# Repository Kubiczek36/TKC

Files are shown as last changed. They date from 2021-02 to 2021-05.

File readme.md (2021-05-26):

# Projekt dalekohledu pro předmět TKC

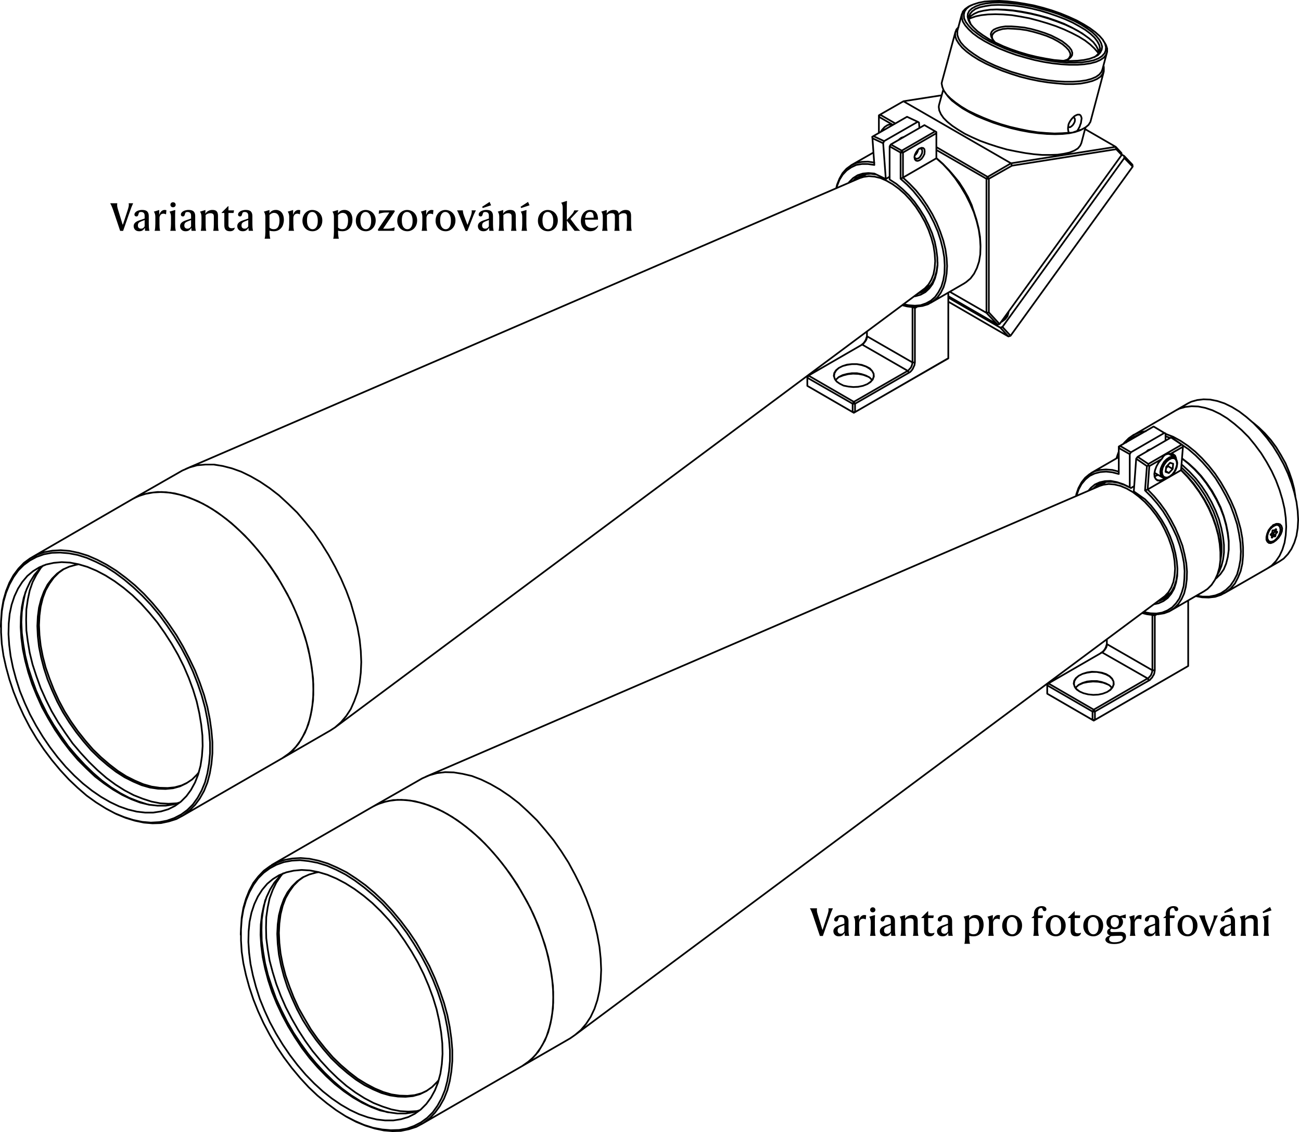
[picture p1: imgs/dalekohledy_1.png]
Dalekohledy


__Co tu naleznete?__

- [Zemax](zemax) - simulace optických vlastností v programu Zemax Optic studio
- [CAD](CAD) - soubory jednotlivých dílů a sestavy v Solidworks
- [imgs](imgs) - ilustrace a obrázky pro tento dokument
- [parts](parts) - dokumentace od výrobce vybraných použitých dílů.

Dalekohled se bude skládat z objektivu a okuláru s určením pro pozemní pozorování. Jako převracecí mechanismus bude použito zrcátko.

[Stránky Meopty](https://eshop.meopta.cz/spektivy/) s inspirací.

## Rozvržení

Konstrukce je inspirována spektivem [Meopta MeoStar S2](https://eshop.meopta.cz/spektivy-meostar-s2/spektiv-meostar-s2-82-hd-sikmy/) tento spektiv má ohniskovou vzdálenost objektivu 439 mm.

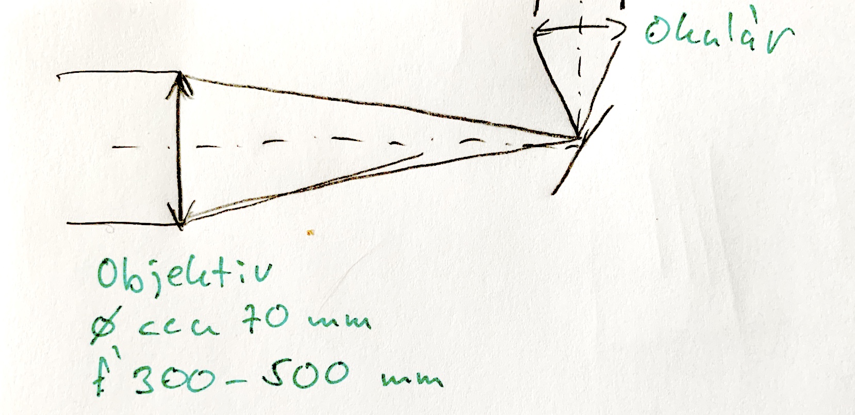
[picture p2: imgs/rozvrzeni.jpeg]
rozvrzeni dalekohledu


Jako objektiv bude sloužit achromatický dublet. Například firma Edmund Optics [nabízí](https://www.edmundoptics.com/c/achromatic-lenses/652/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) takové dublety, které vyhovují průměrem ohniskem. Další výhodou je knihovna dílů v programu Zemax Optics Studio.

Jako okulár se jeví vhodné použít [okulár 20-60x od společnosti Meopta](https://eshop.meopta.cz/spektivy-meostar-s1/okular-20-60x/), navíc spektiv MeoStar S1 má ohniskovou vzdálenost objektivu podobnou námi zvlené vzdálenosti (f' = 329 mm). Díky tomu, že okulár umožňuje zoomovat není zapotřebí měnit okuláry, což umožní redukovat množství prachu, které si při výměně do tubusu dostane.

## Výběr komponent a simulace v programu Zemax

### Objektiv

Z nabídky [vhodných achromatických dubletů](https://www.edmundoptics.com/c/achromatic-lenses/652/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)) firmy Edumnd Optics byl vybrát [dublet](https://www.edmundoptics.com/p/75mm-dia-x-400mm-fl-vis-0deg-coated-achromatic-lens/30848/) s ohniskovou vzdáleností 400 mm a průměru 75 mm s vrstvou propouštející viditelné vlnové délky (400 - 700 nm).

Jelikož je dalekohled určen pro pozemní pozorování, tak je zapotřebí použít jako kameru vhodný fotoaparát. Samotný dublet nemusí mít velké zorné pole, proto stačí použít fotoaparát s čipem micro 4/3, například [Panasonic Lumix GHS5](https://www.fotoskoda.cz/panasonic-lumix-dc-gh5s/). Rozměry čipu 17,3 na 13 mm znemenají, že nejvzdálenější objekt od osy bude 10,8 mm. 

Při simulaci je zapotřebí počítat se závitovým kroužkem upínajícím objektiv do objímky, proto byla zvolena apertura o průměru 73 mm. Při simulaci bylo simulováno zobrazení osového předmětu a dále předmětů vzdálených 1° a 1,5° od osy pro pokrytí celého čipu. 

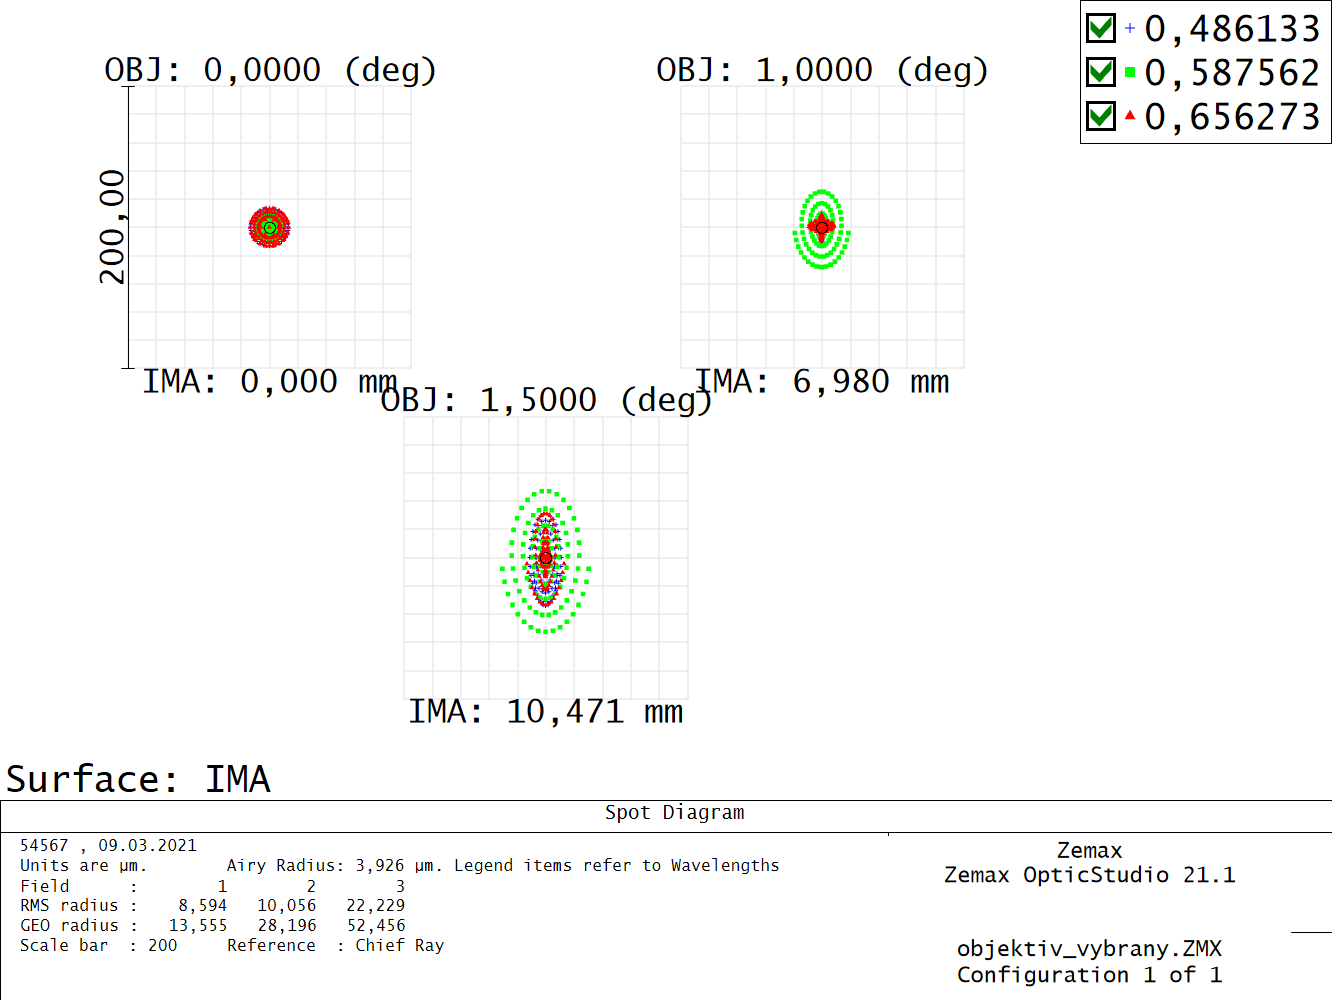
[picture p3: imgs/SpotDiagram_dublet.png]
spot dubletu


Ze spot diagramu lze vidět, že pokud chceme získat kvalitní obraz předmětu umístěného uprostřed zorného pole stačí velikost pixelu okolo 10 μm. To lze ostatně taktéž vidět na závislosti funkce přenosu kontrastu (MTF - Modulated Transfer Funkction) na zorném poli. O clonách pro odstínění parazitních paprsků bude pojednáno později.

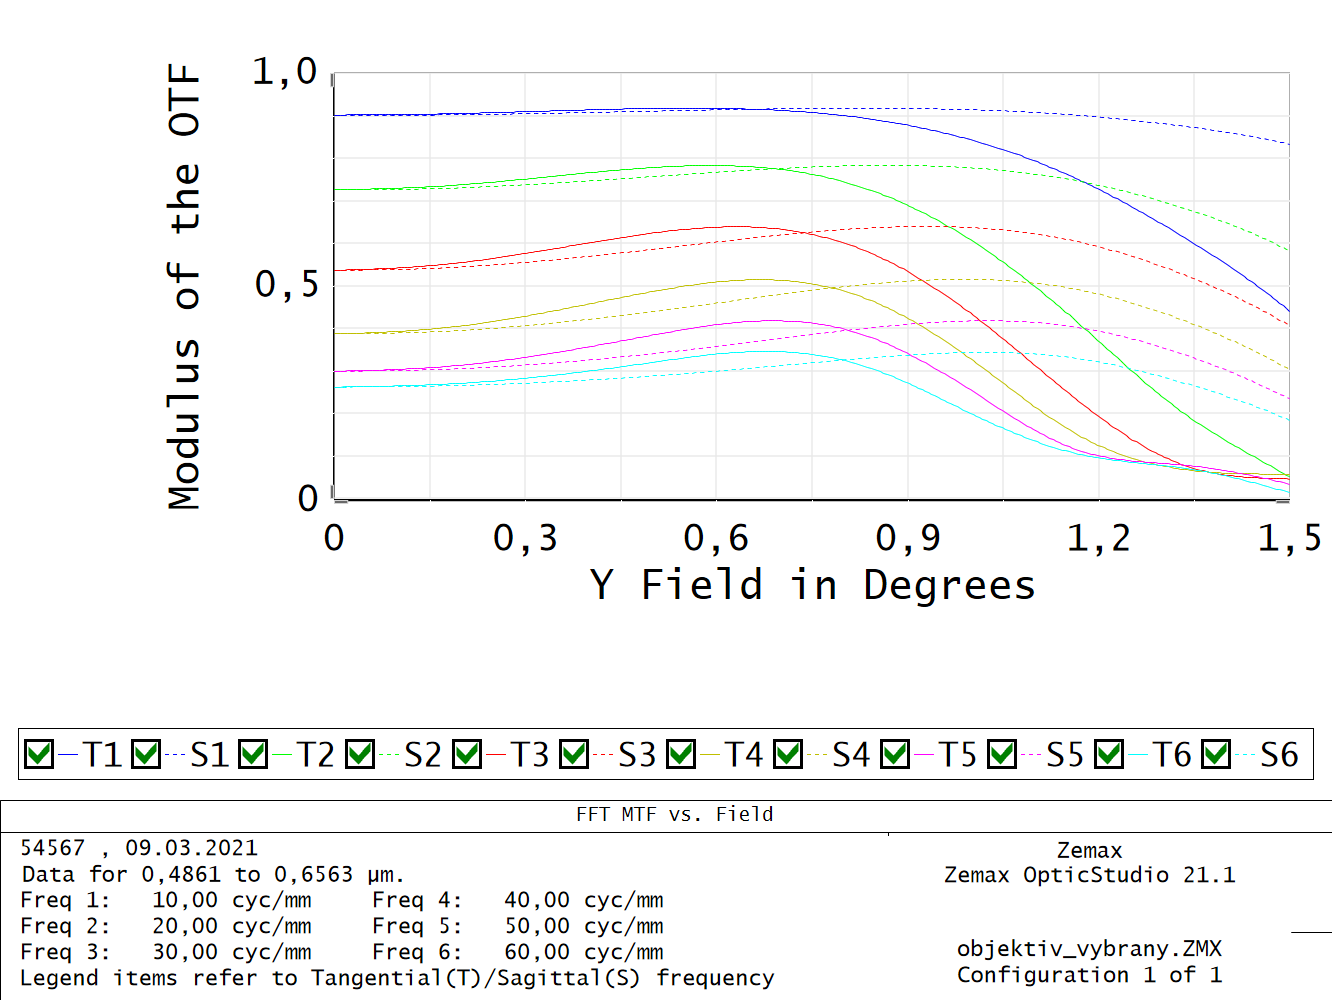
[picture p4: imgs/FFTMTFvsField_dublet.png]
MTF


### Okulár a pozorování okem. 

Při pozorování okem poskytuje samotný objektiv zorné pola max 2,4° Při použití většího zorného pole, je zklenutí pole větší jak podélná sférická vada.

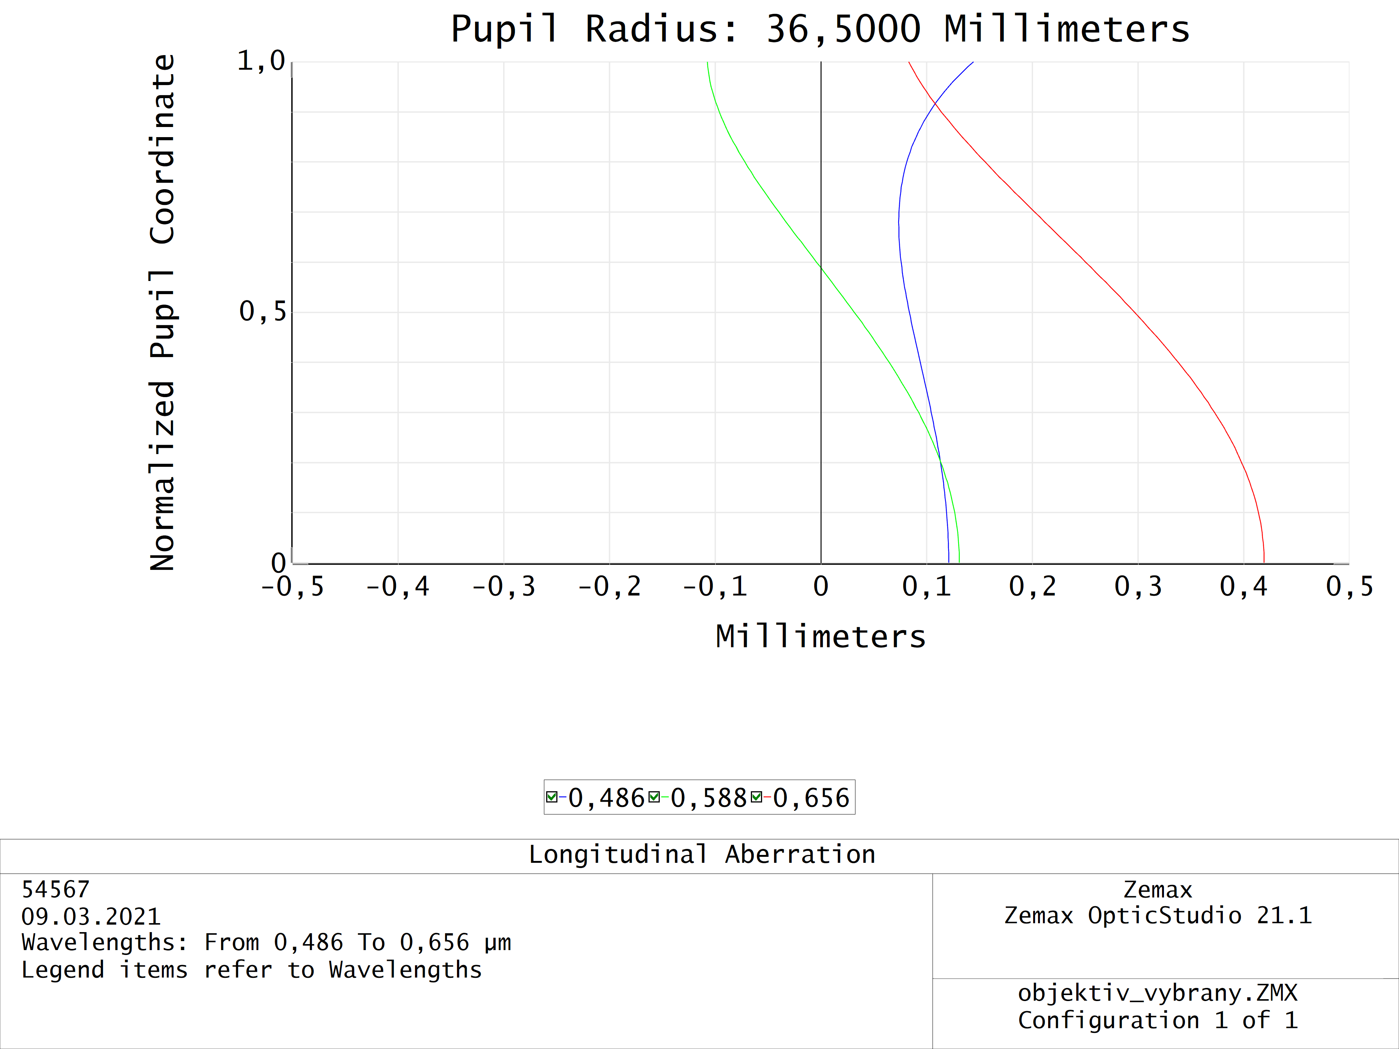
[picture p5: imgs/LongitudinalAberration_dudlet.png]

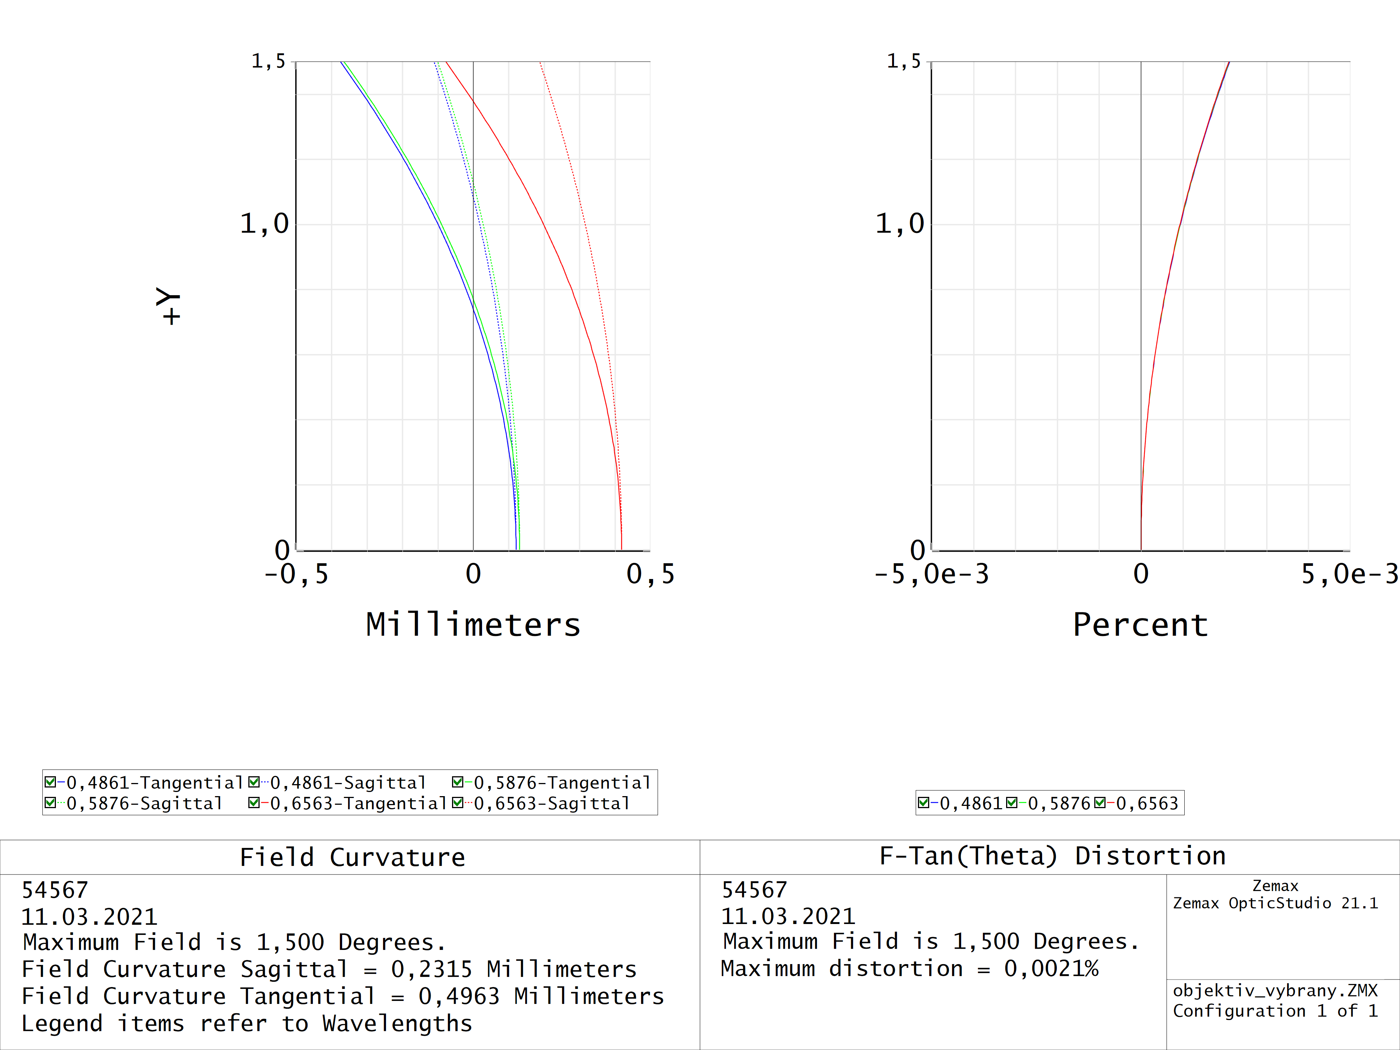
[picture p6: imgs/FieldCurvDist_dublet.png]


Pro převrácení obrazu bylo jako převracecí mechanizmus vybráno zenitové zrcátko. Okulár má ohniskovou vzdálenost 16,2 až 5,55 mm a pro použitý objektiv s ohninskem 400 mm získáváme zorné pole od 1,48° do 0,74° (velikost předmětu v polní rovnině od 5,17 mm do 2,584 mm). Při návrhu mechanické části je počítáno, že ohnisková rovina se nachází v rovině vstupní pupily. Schéma lze vidět na následujícím obrázku.

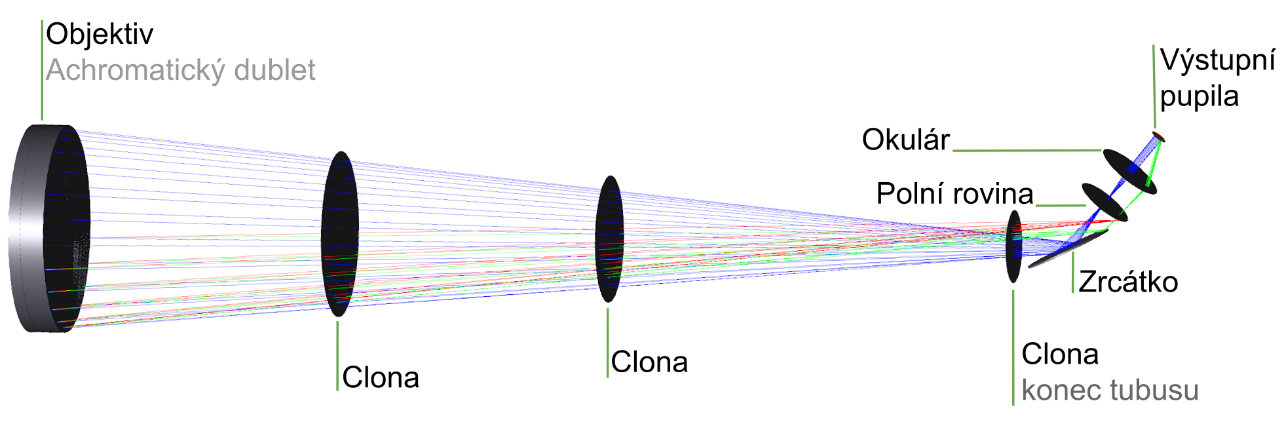
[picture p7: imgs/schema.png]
Schéma dalekohledu


Poloha okuláru je volena tak, aby okulár zobrazoval polní rovinu do konvenční zrakové vzdálenosti 250 mm. Při použití delšího ohniska okuláru (16,2 mm) vzniknou v této rovně stopy velké zhruba 300 μm.
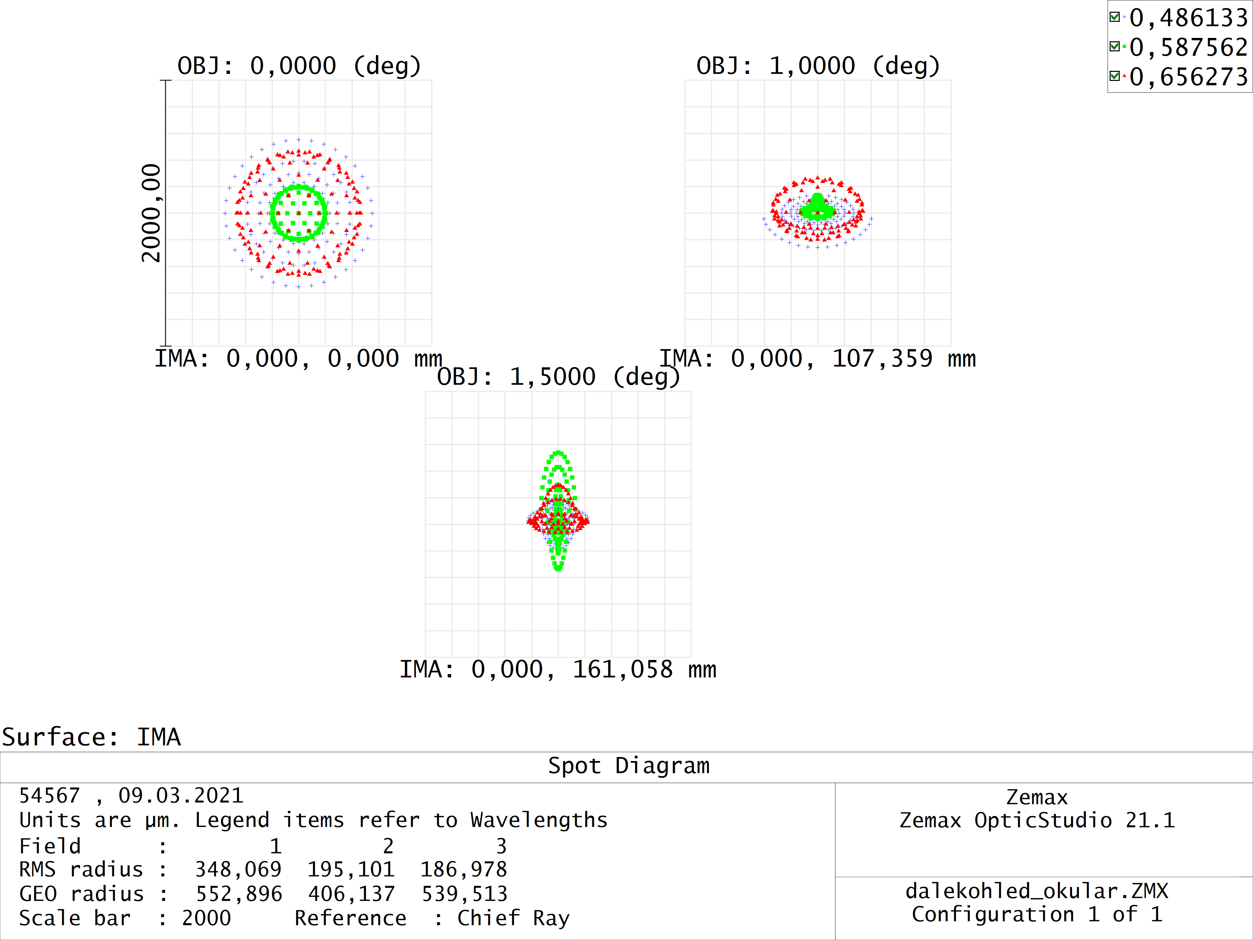
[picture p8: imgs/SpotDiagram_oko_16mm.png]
spot 16 mm


Funkce přenosu kontrastu bude vypadat následujícně.

MTF 16 mm

Při použití nejkratšího ohniska okuláru 5,17 mm se vlivem vinětace omezí zorné pole na zhruba 0,4°.

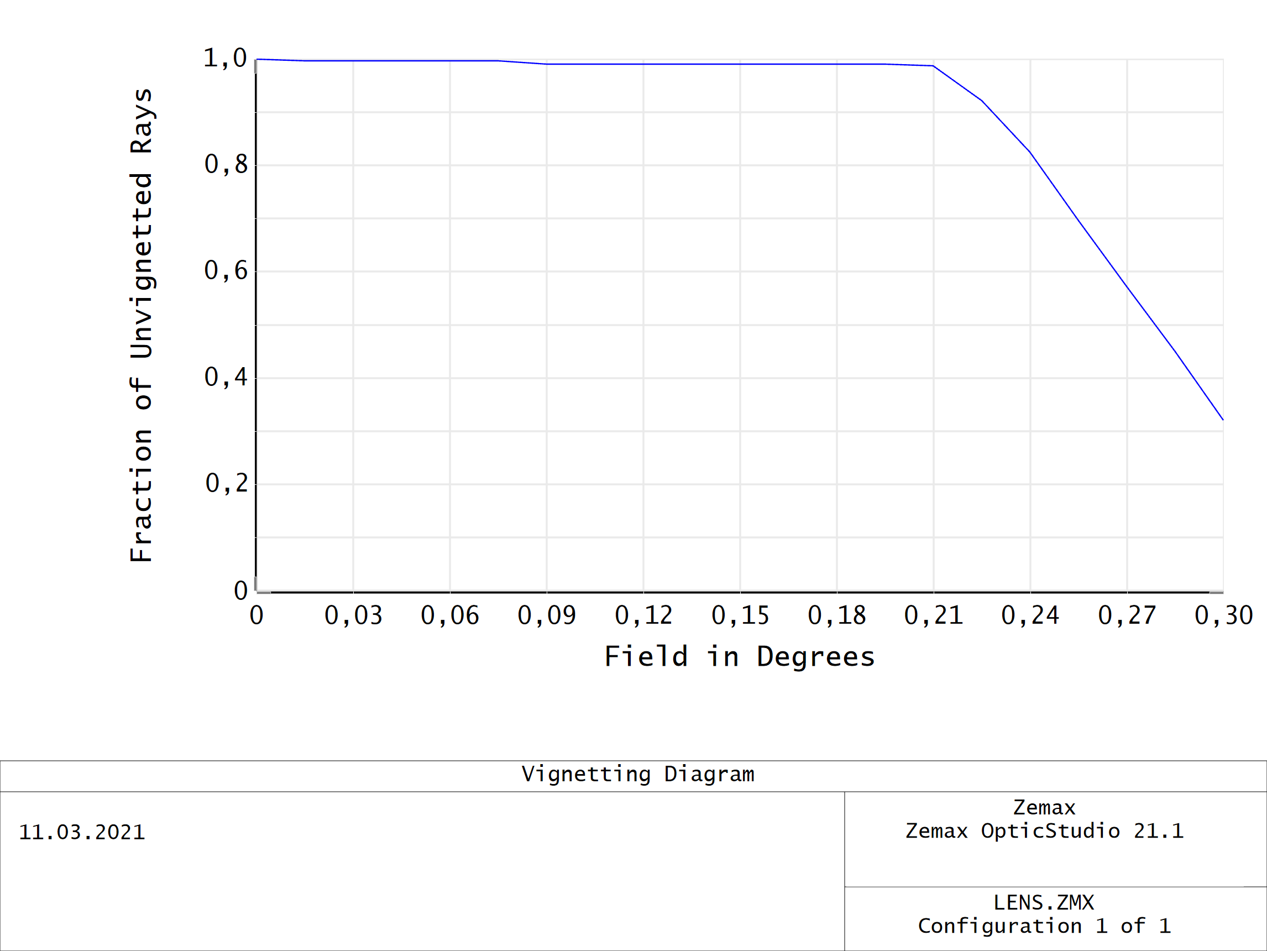
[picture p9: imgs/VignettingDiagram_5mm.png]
Vinětace systému


V této rovině vznikají stopy velké zhruba 300 μm.

### Výpočet ostřícího rozsahu

Z rovnice paraxiální čočky lze vypočítat rozsah výsuvu potřebný pro ostření mězi nekonečněm a předmětem umístěným ve vzdálenosti 20 m. Pro předmět umístěný v 20 metrech vychází obrazová vzdálenost a' = f' + 8,141 mm. Dále je zapotřebí započítat korekci vad oka v rozsahu 4D. Užitím vztahu ze strany 19 [[1](#lit)] zjistíme, že při použití delšího ohniska 16,2 mm vyžaduje korekce vady přidání dalších 0,4 mm k výsuvu a to na obě strany.

|předmnětová vzdálenost| vzdálenost obrazu od ohniska| vzdálenost s korekcí pro 4D|
|---:|---:|---:|
| inf | 0 mm| - 0,400 mm|
|20 m | 8,141 mm | 8,541 mm|

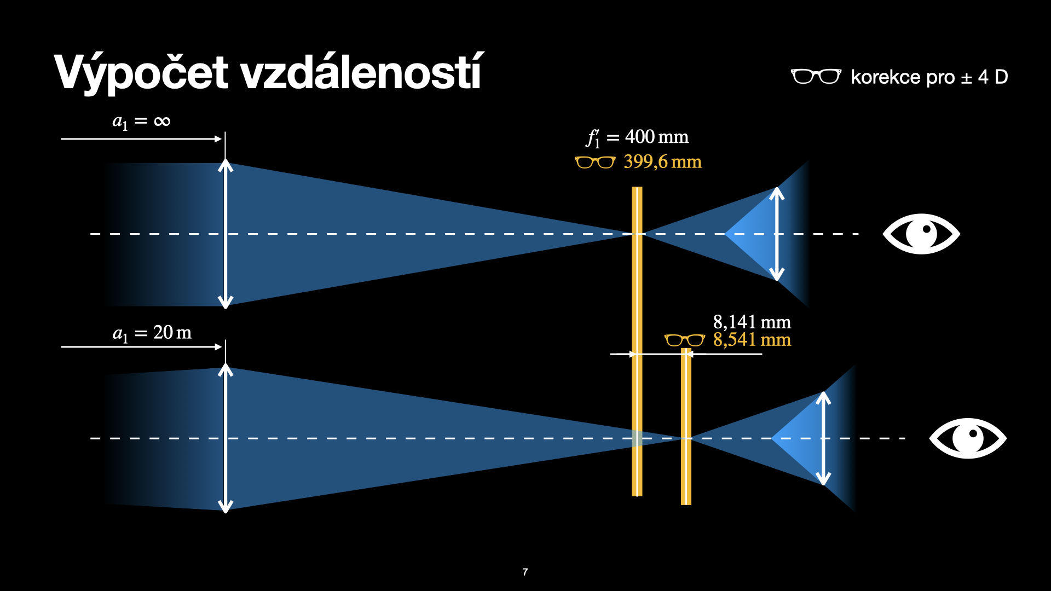
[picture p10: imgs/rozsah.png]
Ostřící rozsah


Při tvorbě mechanického návrhu je dále počítáno s 0,5 mm rezervou, tak aby šlo přeostřit "za nekonečno" i před 20 m.

## Návrh mechanické konstrukce

Pro mechanickou konstrukci jsem volil rozvržení jak lze vidět na obrázku níže. Pro podrobnější vhled doporučuji nahlédnout do [výkresu sestav](CAD/drawings/TKC_000.pdf). 

Dalekohledy

Objektiv je uložen v objímce, která je závitem připojená k tubusu. Detail uložení lze vidět na následujícím obrázku.

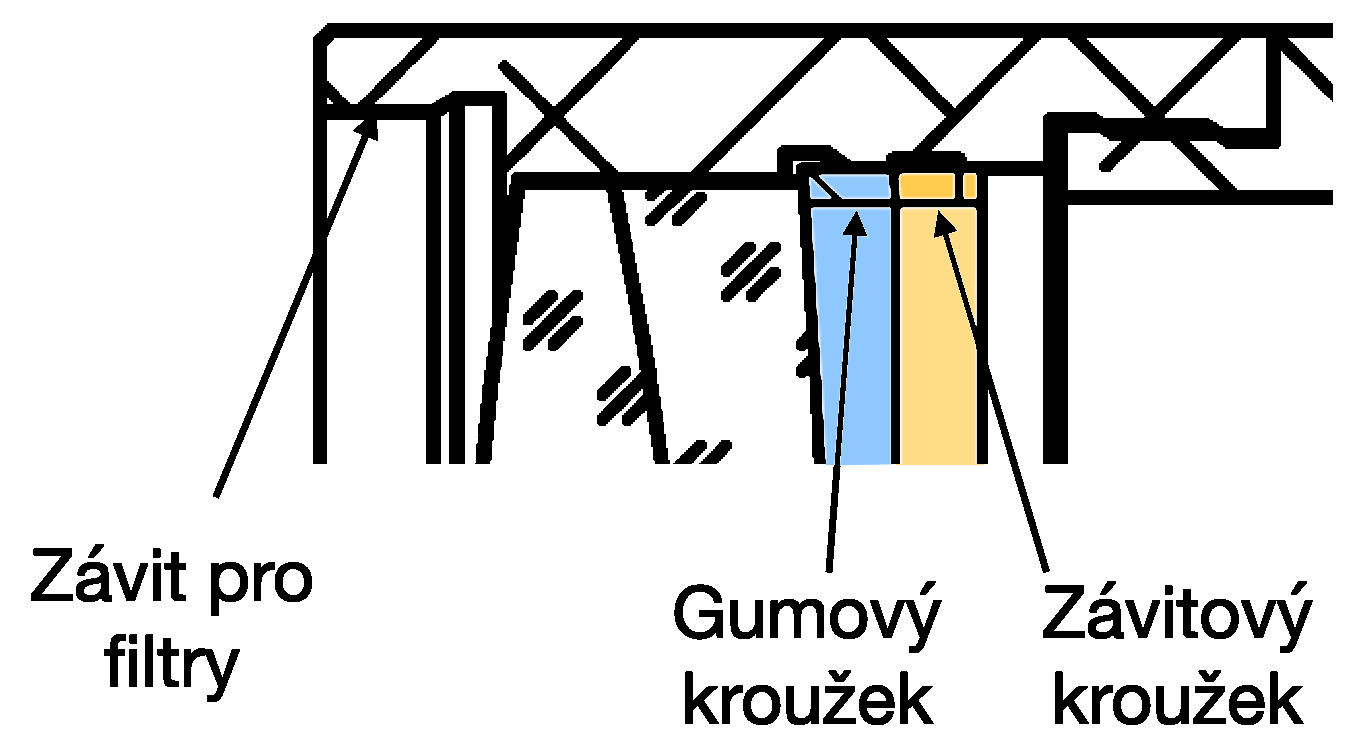
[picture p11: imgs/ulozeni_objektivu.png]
Uložení objektivu


Tubus je nevržený tak, aby tvarem ušetřil materiál a byl zároveň co nejrobustnější. Bohužel však tato konstrukce je obrížně vyrobitelná. Proto pro případ výroby je vhodné vytvořit tubus podle následujícího schématu.

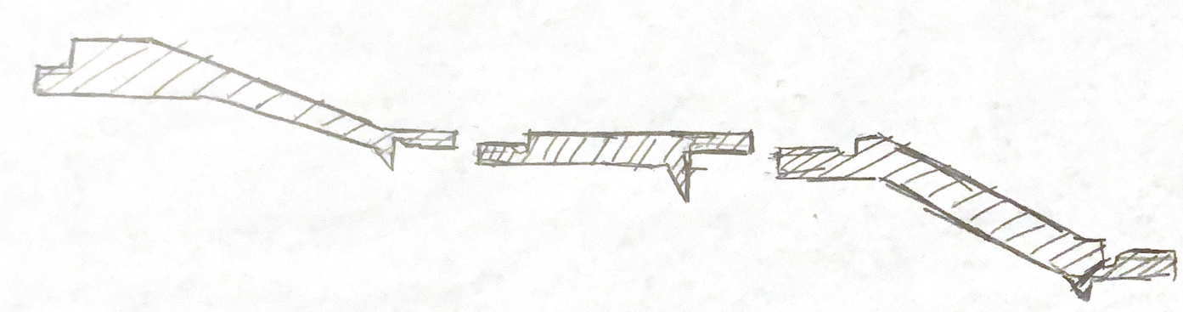
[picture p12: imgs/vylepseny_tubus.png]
Upravený tubus


Každá z částí by byla zhruba 10 cm dlouhá, proto by byla snáze vyrobitelná. Jednotlivé části by byly spojeny závitem a na prostřední rovné části by byla uplá přípojka na stativ, přičmž by pro režim fotografování snadno šlo vyvažovat soustavu.

Uvnitř kostky připojené k tubusu se nachází [eliptické zrcátko](https://www.edmundoptics.com/p/elliptical-mirror-2223mm-minor-axis-protected-aluminum/1919/) od firmy Edmund Optics. Pro obsažení celého pole je zapotřebí zrcátko s hlavní poloosou 14 mm a vedlejší poloosou 8 mm, což vybrané zrcátko pohodlně splňuje.

Zrcátko je upevněno na tříbodém justážním mechanizmu, kdy va šouby s jemným stoupáním tlačí proti pružinkám. Pružinky jsou zajištěny kolíky a jako osa rotace slouží kalená kulička. Destička s zrcátkem je přikryta krytem, aby se dovnitř kostky nedostávaly nečistoty zároveň aby nebyly odkrety justážní šrouby.

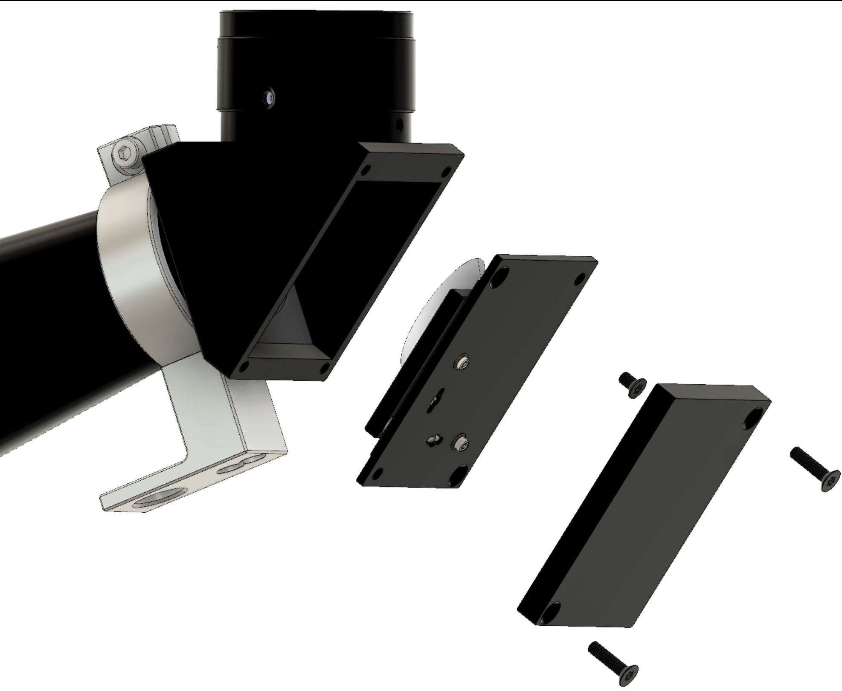
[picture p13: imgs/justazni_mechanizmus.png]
Justážní mechanizmus


Okulárový výsuv je řešen pomocí závitu. Hmatník je pomocí dvou C-prstenců připevněn k statickému dílu a pomocí závitu na vnitřní straně se posouvá vnitřní díl. Ve vnitřním dílu je drážka, která omezuje pohyb dílu.

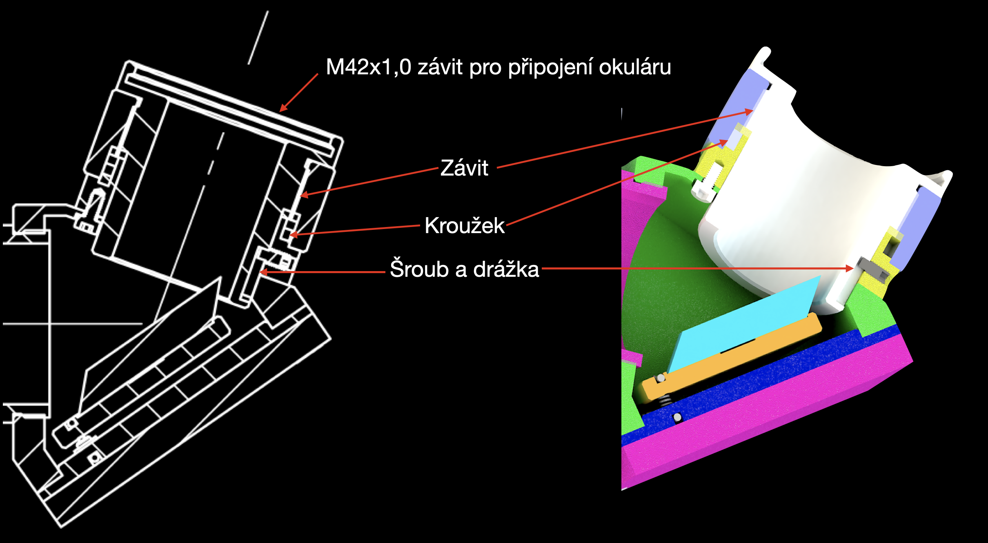
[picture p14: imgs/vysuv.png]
Výsuv


Při fotografování je zapotřebí odšroubovat kostku se zenitovým zrcátkem a připojit výsuv zakončený M42 bajonetem. Výsuv je řešen obdobně jako v případě okuláru.

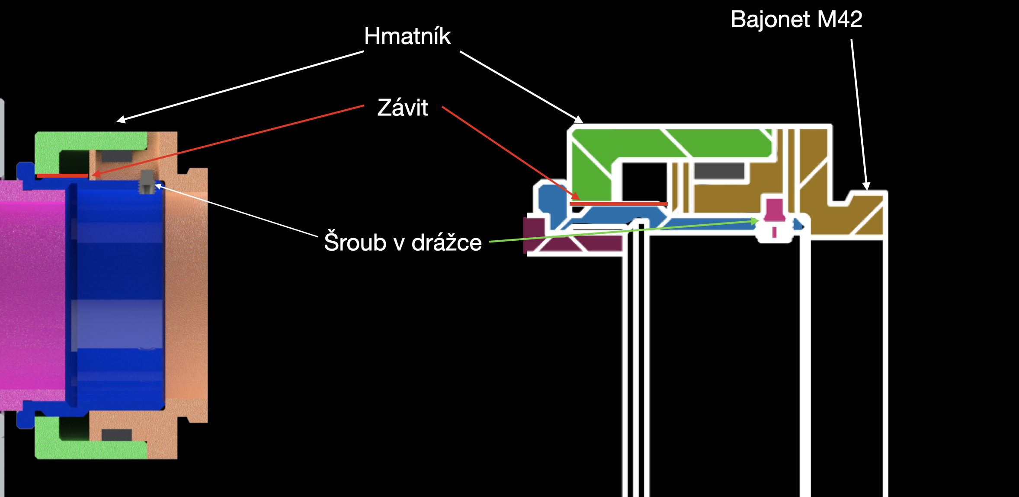
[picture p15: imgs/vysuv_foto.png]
Fotografický výsuv


### Materiály a další úpravy

Jako materiál byla u většiny dílů volena hliníková slitina EN AW 2030 nebo 5083. Díly je zapotřebí po obrábění eloxovat. Pro případné požadavky přesné výroby vybraných ploch je vhodné nechat před eloxací drobný přídavek a požadované plochy po eloxaci doobrobit. 

## Závěr

Byl úspěšně navržen čočkový dalekohled keplerova typu. Pro dalekohled byl vybrán vhodný objektiv a okulár. Pomocí počítačové simulace byly zjištěny jeho optické vlastnosti. Následně bylo vypočítán rozsah výsuvu potřebný pro pozorování objektů mezi nekonečnem a 20m. Byl vypočítán rozsah potřebný pro korekci zrakových vad do 4 D. Následně byla navržena mechanická konstrukce dalekohledu. Pro potřeby výroby byly vytvořeny výrobní výkresy vybraných dílů a výkres sestavy.

## Literatura 

[1] Liška Miroslav: _Optické sešity_ [cit. 24.5.2021] url: http://physics.fme.vutbr.cz/files/vyuka/OptPristroje/OP7_Zakladni%20opticke%20pristroje.pdf

[2] Fuka Josef, Havelka Bedřich: _Optika a atomová fyzika_. SPN Praha 1961.

[3] Born Max, Wolf Emil: _Principles of optics_. Seventh anniversary ed, Cambridge University Press 2019.

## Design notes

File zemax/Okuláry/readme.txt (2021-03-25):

okular ???   - samotný okulár podle výkresu výrobce 
                https://www.edmundoptics.com/p/8mm-efl-mounted-rke-precision-eyepiece/1918/
                a 
                https://www.edmundoptics.com/p/28mm-efl-mounted-rke-precision-eyepiece/1913/    tenot okulár mi ale vyšel s ohniskovou dálkou 29 mm!
                
všimněte si prosím, že STOP povrch je prakticky v ohniskové rovině okuláru.                

dalekohled ????
   okulár je připojen k paraxiální čočce s ohniskouvou dálkou 300 mm pro simulaci dalekohledu. STOP povrch je na objektivové čočce.

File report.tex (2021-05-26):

% Options for packages loaded elsewhere
\PassOptionsToPackage{unicode}{hyperref}
\PassOptionsToPackage{hyphens}{url}
%
\documentclass[
]{article}
\usepackage{lmodern}
\usepackage{amssymb,amsmath}
\usepackage{ifxetex,ifluatex}
\ifnum 0\ifxetex 1\fi\ifluatex 1\fi=0 % if pdftex
  \usepackage[T1]{fontenc}
  \usepackage[utf8]{inputenc}
  \usepackage{textcomp} % provide euro and other symbols
\else % if luatex or xetex
  \usepackage{unicode-math}
  \defaultfontfeatures{Scale=MatchLowercase}
  \defaultfontfeatures[\rmfamily]{Ligatures=TeX,Scale=1}
\fi
% Use upquote if available, for straight quotes in verbatim environments
\IfFileExists{upquote.sty}{\usepackage{upquote}}{}
\IfFileExists{microtype.sty}{% use microtype if available
  \usepackage[]{microtype}
  \UseMicrotypeSet[protrusion]{basicmath} % disable protrusion for tt fonts
}{}
\makeatletter
\@ifundefined{KOMAClassName}{% if non-KOMA class
  \IfFileExists{parskip.sty}{%
    \usepackage{parskip}
  }{% else
    \setlength{\parindent}{0pt}
    \setlength{\parskip}{6pt plus 2pt minus 1pt}}
}{% if KOMA class
  \KOMAoptions{parskip=half}}
\makeatother
\usepackage{xcolor}
\IfFileExists{xurl.sty}{\usepackage{xurl}}{} % add URL line breaks if available
\IfFileExists{bookmark.sty}{\usepackage{bookmark}}{\usepackage{hyperref}}
\hypersetup{
  hidelinks,
  pdfcreator={LaTeX via pandoc}}
\urlstyle{same} % disable monospaced font for URLs
\usepackage{longtable,booktabs}
% Correct order of tables after \paragraph or \subparagraph
\usepackage{etoolbox}
\makeatletter
\patchcmd\longtable{\par}{\if@noskipsec\mbox{}\fi\par}{}{}
\makeatother
% Allow footnotes in longtable head/foot
\IfFileExists{footnotehyper.sty}{\usepackage{footnotehyper}}{\usepackage{footnote}}
\makesavenoteenv{longtable}
\usepackage{graphicx}
\makeatletter
\def\maxwidth{\ifdim\Gin@nat@width>\linewidth\linewidth\else\Gin@nat@width\fi}
\def\maxheight{\ifdim\Gin@nat@height>\textheight\textheight\else\Gin@nat@height\fi}
\makeatother
% Scale images if necessary, so that they will not overflow the page
% margins by default, and it is still possible to overwrite the defaults
% using explicit options in \includegraphics[width, height, ...]{}
\setkeys{Gin}{width=\maxwidth,height=\maxheight,keepaspectratio}
% Set default figure placement to htbp
\makeatletter
\def\fps@figure{htbp}
\makeatother
\setlength{\emergencystretch}{3em} % prevent overfull lines
\providecommand{\tightlist}{%
  \setlength{\itemsep}{0pt}\setlength{\parskip}{0pt}}
\setcounter{secnumdepth}{-\maxdimen} % remove section numbering

\author{Jakub Dokulil}
\date{2021}

\usepackage[czech]{babel}

\begin{document}

\hypertarget{projekt-dalekohledu-pro-pux159edmux11bt-tkc}{%
\section{Projekt dalekohledu pro předmět
TKC}\label{projekt-dalekohledu-pro-pux159edmux11bt-tkc}}

Jakub Dokulil, 2021

\begin{figure}
\centering

\caption{Dalekohledy}
\end{figure}

\section*{Úvod}
Cílem tohoto projektu je navrhnout dalekohled keplerova uspočádání. Čili dalekohled se bude skládat z objektivu a okuláru s určením pro pozemní pozorování. Jako převracecí mechanismus bude použito zrcátko. Inspiraci jsem si vzal z dalekohledu od společnosti \href{https://eshop.meopta.cz/spektivy/}{Meopta}.

\hypertarget{rozvrux17eenuxed}{%
\subsection{Rozvržení}\label{rozvrux17eenuxed}}

Konstrukce je inspirována spektivem
\href{https://eshop.meopta.cz/spektivy-meostar-s2/spektiv-meostar-s2-82-hd-sikmy/}{Meopta
MeoStar S2} tento spektiv má ohniskovou vzdálenost objektivu 439 mm.

\begin{figure}
\centering

\caption{rozvrzeni dalekohledu}
\end{figure}

Jako objektiv bude sloužit achromatický dublet. Například firma Edmund
Optics
\href{https://www.edmundoptics.com/c/achromatic-lenses/652/\#29374=29374_s\%3ANS4wMCAtIDUuOTk1\&29374=29374_s\%3ANC4wMCAtIDQuOTk1\&27560=27560_s\%3AVklTIDAmZGVnOyAoNDI1LTY3NW5tKQ2\&27560=27560_s\%3AVklTLU5JUiAoNDAwLTEwMDBubSk1\&27560=27560_s\%3ATWdGPHN1Yj4yPC9zdWI-ICg0MDAtNzAwbm0p0\&27560=27560_s\%3ATWdGPHN1Yj4yPC9zdWI-ICg0MDAtNzAwbm0p0\&27560=27560_s\%3AVklTIDAmZGVnOyAoNDI1LTY3NW5tKQ2\&27560=27560_s\%3AVklTLU5JUiAoNDAwLTEwMDBubSk1\&27560=27560_s\%3AVVYtVklTICgzNDUtNzAwbm0p0\&27614=27614_d\%3A\%5B59.18\%20TO\%2089.47\%5D}{nabízí}
takové dublety, které vyhovují průměrem ohniskem. Další výhodou je
knihovna dílů v programu Zemax Optics Studio.

Jako okulár se jeví vhodné použít
\href{https://eshop.meopta.cz/spektivy-meostar-s1/okular-20-60x/}{okulár
20-60x od společnosti Meopta}, navíc spektiv MeoStar S1 má ohniskovou
vzdálenost objektivu podobnou námi zvlené vzdálenosti (f' = 329 mm).
Díky tomu, že okulár umožňuje zoomovat není zapotřebí měnit okuláry, což
umožní redukovat množství prachu, které si při výměně do tubusu dostane.

\hypertarget{vuxfdbux11br-komponent-a-simulace-v-programu-zemax}{%
\subsection{Výběr komponent a simulace v programu
Zemax}\label{vuxfdbux11br-komponent-a-simulace-v-programu-zemax}}

\hypertarget{objektiv}{%
\subsubsection{Objektiv}\label{objektiv}}

Z nabídky
\href{https://www.edmundoptics.com/c/achromatic-lenses/652/\#29374=29374_s\%3ANS4wMCAtIDUuOTk1\&29374=29374_s\%3ANC4wMCAtIDQuOTk1\&27560=27560_s\%3AVklTIDAmZGVnOyAoNDI1LTY3NW5tKQ2\&27560=27560_s\%3AVklTLU5JUiAoNDAwLTEwMDBubSk1\&27560=27560_s\%3ATWdGPHN1Yj4yPC9zdWI-ICg0MDAtNzAwbm0p0\&27560=27560_s\%3ATWdGPHN1Yj4yPC9zdWI-ICg0MDAtNzAwbm0p0\&27560=27560_s\%3AVklTIDAmZGVnOyAoNDI1LTY3NW5tKQ2\&27560=27560_s\%3AVklTLU5JUiAoNDAwLTEwMDBubSk1\&27560=27560_s\%3AVVYtVklTICgzNDUtNzAwbm0p0\&27614=27614_d\%3A\%5B59.18\%20TO\%2089.47\%5D}{vhodných
achromatických dubletů}) firmy Edumnd Optics byl vybrát
\href{https://www.edmundoptics.com/p/75mm-dia-x-400mm-fl-vis-0deg-coated-achromatic-lens/30848/}{dublet}
s ohniskovou vzdáleností 400 mm a průměru 75 mm s vrstvou propouštející
viditelné vlnové délky (400 - 700 nm).

Jelikož je dalekohled určen pro pozemní pozorování, tak je zapotřebí
použít jako kameru vhodný fotoaparát. Samotný dublet nemusí mít velké
zorné pole, proto stačí použít fotoaparát s čipem micro 4/3, například
\href{https://www.fotoskoda.cz/panasonic-lumix-dc-gh5s/}{Panasonic Lumix
GHS5}. Rozměry čipu 17,3 na 13 mm znemenají, že nejvzdálenější objekt od
osy bude 10,8 mm.

Při simulaci je zapotřebí počítat se závitovým kroužkem upínajícím
objektiv do objímky, proto byla zvolena apertura o průměru 73 mm. Při
simulaci bylo simulováno zobrazení osového předmětu a dále předmětů
vzdálených 1° a 1,5° od osy pro pokrytí celého čipu.

\begin{figure}
\centering

\caption{spot dubletu}
\end{figure}

Ze spot diagramu lze vidět, že pokud chceme získat kvalitní obraz
předmětu umístěného uprostřed zorného pole stačí velikost pixelu okolo
10 μm. To lze ostatně taktéž vidět na závislosti funkce přenosu
kontrastu (MTF - Modulated Transfer Funkction) na zorném poli. O clonách
pro odstínění parazitních paprsků bude pojednáno později.

\begin{figure}
\centering

\caption{MTF}
\end{figure}

\hypertarget{okuluxe1r-a-pozorovuxe1nuxed-okem.}{%
\subsubsection{Okulár a pozorování
okem.}\label{okuluxe1r-a-pozorovuxe1nuxed-okem.}}

Při pozorování okem poskytuje samotný objektiv zorné pola max 2,4° Při
použití většího zorného pole, je zklenutí pole větší jak podélná
sférická vada.




Pro převrácení obrazu bylo jako převracecí mechanizmus vybráno zenitové
zrcátko. Okulár má ohniskovou vzdálenost 16,2 až 5,55 mm a pro použitý
objektiv s ohninskem 400 mm získáváme zorné pole od 1,48° do 0,74°
(velikost předmětu v polní rovnině od 5,17 mm do 2,584 mm). Při návrhu
mechanické části je počítáno, že ohnisková rovina se nachází v rovině
vstupní pupily. Schéma lze vidět na následujícím obrázku.

\begin{figure}
\centering

\caption{Schéma dalekohledu}
\end{figure}

Poloha okuláru je volena tak, aby okulár zobrazoval polní rovinu do
konvenční zrakové vzdálenosti 250 mm. Při použití delšího ohniska
okuláru (16,2 mm) vzniknou v této rovně stopy velké zhruba 300 μm.


Funkce přenosu kontrastu bude vypadat následujícně.

\begin{figure}
\centering

\caption{MTF 16 mm}
\end{figure}

Při použití nejkratšího ohniska okuláru 5,17 mm se vlivem vinětace omezí
zorné pole na zhruba 0,4°.

\begin{figure}
\centering

\caption{Vinětace systému}
\end{figure}

V této rovině vznikají stopy velké zhruba 300 μm.

\hypertarget{vuxfdpoux10det-ostux159uxedcuxedho-rozsahu}{%
\subsubsection{Výpočet ostřícího
rozsahu}\label{vuxfdpoux10det-ostux159uxedcuxedho-rozsahu}}

Z rovnice paraxiální čočky lze vypočítat rozsah výsuvu potřebný pro
ostření mězi nekonečněm a předmětem umístěným ve vzdálenosti 20 m. Pro
předmět umístěný v 20 metrech vychází obrazová vzdálenost a' = f' +
8,141 mm. Dále je zapotřebí započítat korekci vad oka v rozsahu 4D.
Užitím vztahu ze strany 19 {[}\protect\hyperlink{lit}{1}{]} zjistíme, že
při použití delšího ohniska 16,2 mm vyžaduje korekce vady přidání
dalších 0,4 mm k výsuvu a to na obě strany.

\begin{longtable}[]{@{}rrr@{}}
\toprule
\begin{minipage}[b]{0.33\columnwidth}\raggedleft
předmnětová vzdálenost\strut
\end{minipage} & \begin{minipage}[b]{0.43\columnwidth}\raggedleft
vzdálenost obrazu od ohniska\strut
\end{minipage} & \begin{minipage}[b]{0.15\columnwidth}\raggedleft
vzdálenost s korekcí pro 4D\strut
\end{minipage}\tabularnewline
\midrule
\endhead
\begin{minipage}[t]{0.33\columnwidth}\raggedleft
inf\strut
\end{minipage} & \begin{minipage}[t]{0.43\columnwidth}\raggedleft
0 mm\strut
\end{minipage} & \begin{minipage}[t]{0.15\columnwidth}\raggedleft
- 0,400 mm\strut
\end{minipage}\tabularnewline
\begin{minipage}[t]{0.33\columnwidth}\raggedleft
20 m\strut
\end{minipage} & \begin{minipage}[t]{0.43\columnwidth}\raggedleft
8,141 mm\strut
\end{minipage} & \begin{minipage}[t]{0.15\columnwidth}\raggedleft
8,541 mm\strut
\end{minipage}\tabularnewline
\bottomrule
\end{longtable}

\begin{figure}
\centering

\caption{Ostřící rozsah}
\end{figure}

Při tvorbě mechanického návrhu je dále počítáno s 0,5 mm rezervou, tak
aby šlo přeostřit ``za nekonečno'' i před 20 m.

\hypertarget{nuxe1vrh-mechanickuxe9-konstrukce}{%
\subsection{Návrh mechanické
konstrukce}\label{nuxe1vrh-mechanickuxe9-konstrukce}}

Pro mechanickou konstrukci jsem volil rozvržení jak lze vidět na obrázku
níže. Pro podrobnější vhled doporučuji nahlédnout do
\href{CAD/drawings/TKC_000.pdf}{výkresu sestav}.

\begin{figure}
\centering

\caption{Dalekohledy}
\end{figure}

Objektiv je uložen v objímce, která je závitem připojená k tubusu.
Detail uložení lze vidět na následujícím obrázku.

\begin{figure}
\centering

\caption{Uložení objektivu}
\end{figure}

Tubus je nevržený tak, aby tvarem ušetřil materiál a byl zároveň co
nejrobustnější. Bohužel však tato konstrukce je obrížně vyrobitelná.
Proto pro případ výroby je vhodné vytvořit tubus podle následujícího
schématu. Tubus má uvnitř rýhování pro zamezení šíření parazitních paprsků.

\begin{figure}
\centering

\caption{Upravený tubus}
\end{figure}

Každá z částí by byla zhruba 10 cm dlouhá, proto by byla snáze
vyrobitelná. Jednotlivé části by byly spojeny závitem a na prostřední
rovné části by byla uplá přípojka na stativ, přičmž by pro režim
fotografování snadno šlo vyvažovat soustavu.

Uvnitř kostky připojené k tubusu se nachází
\href{https://www.edmundoptics.com/p/elliptical-mirror-2223mm-minor-axis-protected-aluminum/1919/}{eliptické
zrcátko} od firmy Edmund Optics. Pro obsažení celého pole je zapotřebí
zrcátko s hlavní poloosou 14 mm a vedlejší poloosou 8 mm, což vybrané
zrcátko pohodlně splňuje.

Zrcátko je upevněno na tříbodém justážním mechanizmu, kdy va šouby s
jemným stoupáním tlačí proti pružinkám. Pružinky jsou zajištěny kolíky a
jako osa rotace slouží kalená kulička. Destička s zrcátkem je přikryta
krytem, aby se dovnitř kostky nedostávaly nečistoty zároveň aby nebyly
odkrety justážní šrouby.

\begin{figure}
\centering

\caption{Justážní mechanizmus}
\end{figure}

Okulárový výsuv je řešen pomocí závitu. Hmatník je pomocí dvou
C-prstenců připevněn k statickému dílu a pomocí závitu na vnitřní straně
se posouvá vnitřní díl. Ve vnitřním dílu je drážka, která omezuje pohyb
dílu.

\begin{figure}
\centering

\caption{Výsuv}
\end{figure}

Při fotografování je zapotřebí odšroubovat kostku se zenitovým zrcátkem
a připojit výsuv zakončený M42 bajonetem. Výsuv je řešen obdobně jako v
případě okuláru.

\begin{figure}
\centering

\caption{Fotografický výsuv}
\end{figure}

\hypertarget{materiuxe1ly-a-dalux161uxed-uxfapravy}{%
\subsubsection{Materiály a další
úpravy}\label{materiuxe1ly-a-dalux161uxed-uxfapravy}}

Jako materiál byla u většiny dílů volena hliníková slitina EN AW 2030
nebo 5083. Díly je zapotřebí po obrábění eloxovat. Pro případné
požadavky přesné výroby vybraných ploch je vhodné nechat před eloxací
drobný přídavek a požadované plochy po eloxaci doobrobit.

\hypertarget{materiuxe1ly-a-dalux161uxed-uxfapravy}{%
\subsubsection{Příslušenství}\label{materiuxe1ly-a-dalux161uxed-uxfapravy}}

Jako příslušenství je k dalekohledu dodáván stativová přípojka s čtvrtpalcovým závitem. Taktéž je součástí návrhu sluneční clona, vyrobená z polykarbonátu

\hypertarget{zuxe1vux11br}{%
\subsection{Závěr}\label{zuxe1vux11br}}

Byl úspěšně navržen čočkový dalekohled keplerova typu. Pro dalekohled
byl vybrán vhodný objektiv a okulár. Pomocí počítačové simulace byly
zjištěny jeho optické vlastnosti. Následně bylo vypočítán rozsah výsuvu
potřebný pro pozorování objektů mezi nekonečnem a 20m. Byl vypočítán
rozsah potřebný pro korekci zrakových vad do 4 D. Následně byla navržena
mechanická konstrukce dalekohledu. Pro potřeby výroby byly vytvořeny
výrobní výkresy vybraných dílů a výkres sestavy.

\hypertarget{literatura}{%
\subsection{\texorpdfstring{Literatura
}{Literatura }}\label{literatura}}

{[}1{]} Liška Miroslav: \emph{Optické sešity} {[}cit. 24.5.2021{]} url:
http://physics.fme.vutbr.cz/files/vyuka/OptPristroje/OP7\_Zakladni\%20opticke\%20pristroje.pdf

{[}2{]} Fuka Josef, Havelka Bedřich: \emph{Optika a atomová fyzika}. SPN
Praha 1961.

{[}3{]} Born Max, Wolf Emil: \emph{Principles of optics}. Seventh
anniversary ed, Cambridge University Press 2019.

\end{document}

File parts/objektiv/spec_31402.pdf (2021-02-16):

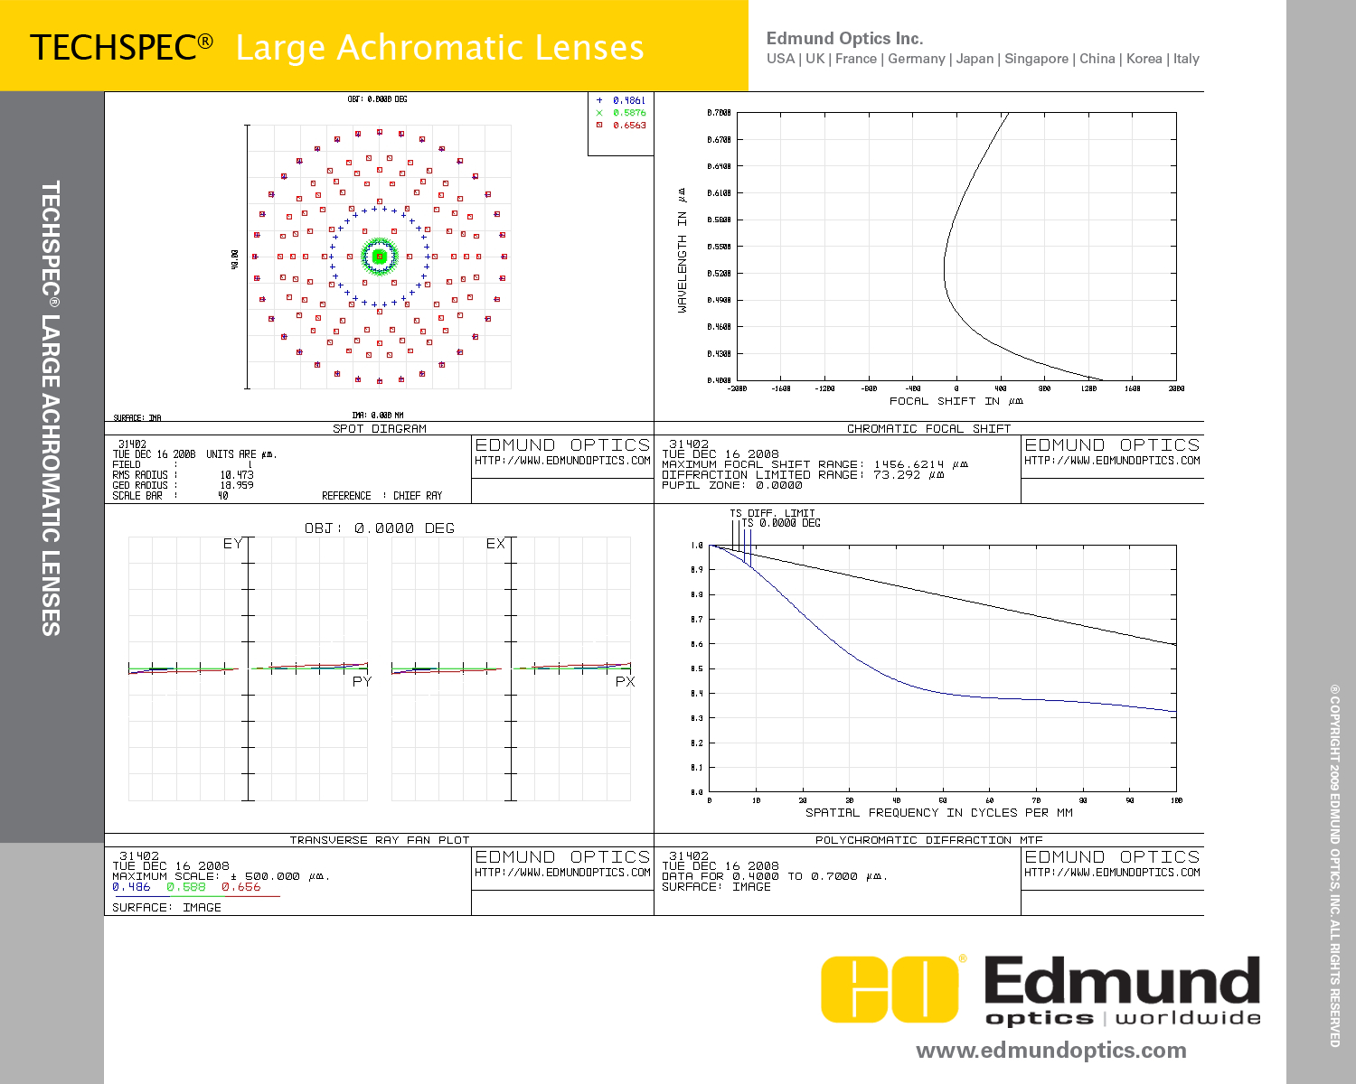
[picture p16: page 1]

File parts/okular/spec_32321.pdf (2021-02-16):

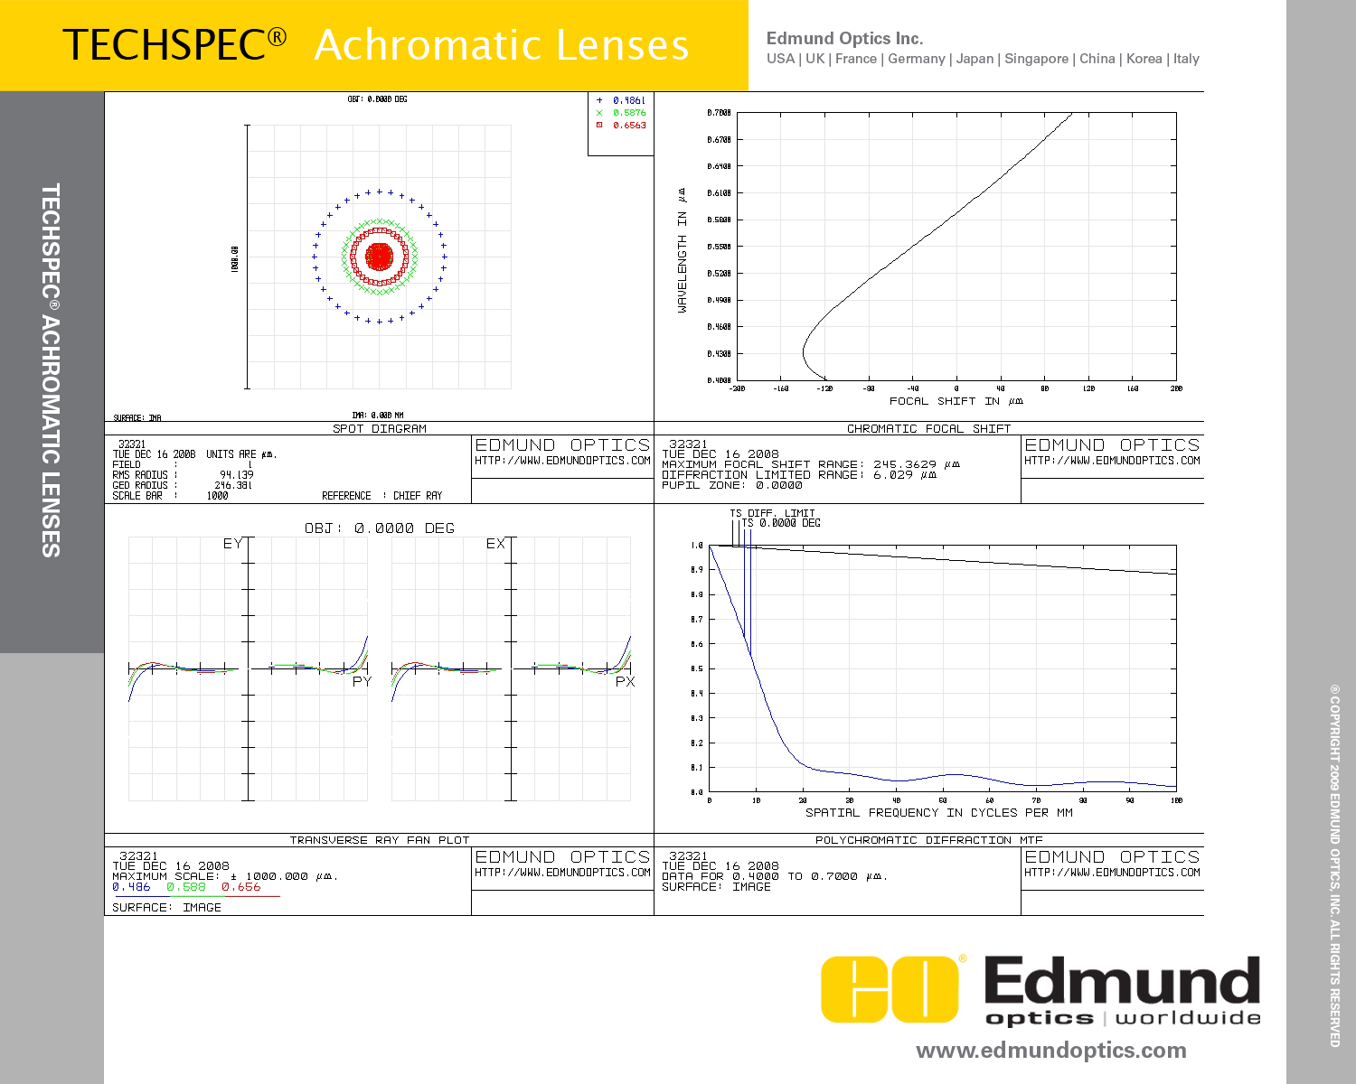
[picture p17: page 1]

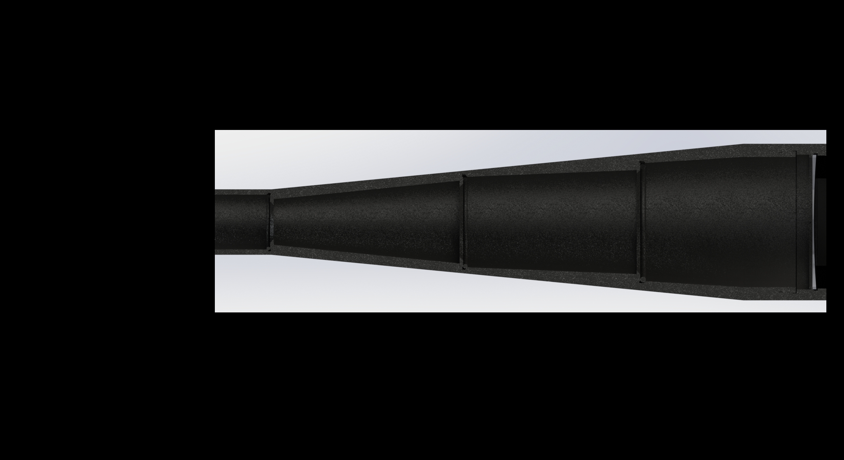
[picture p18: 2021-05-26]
imgs/render_1.JPG

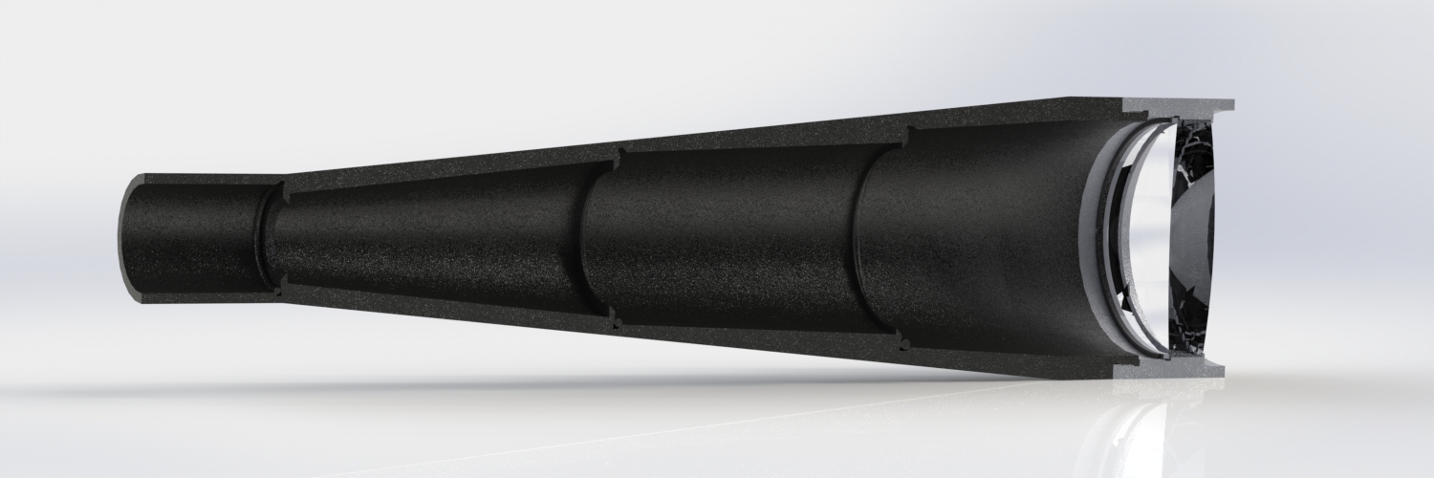
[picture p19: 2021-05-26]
imgs/render_8.JPG

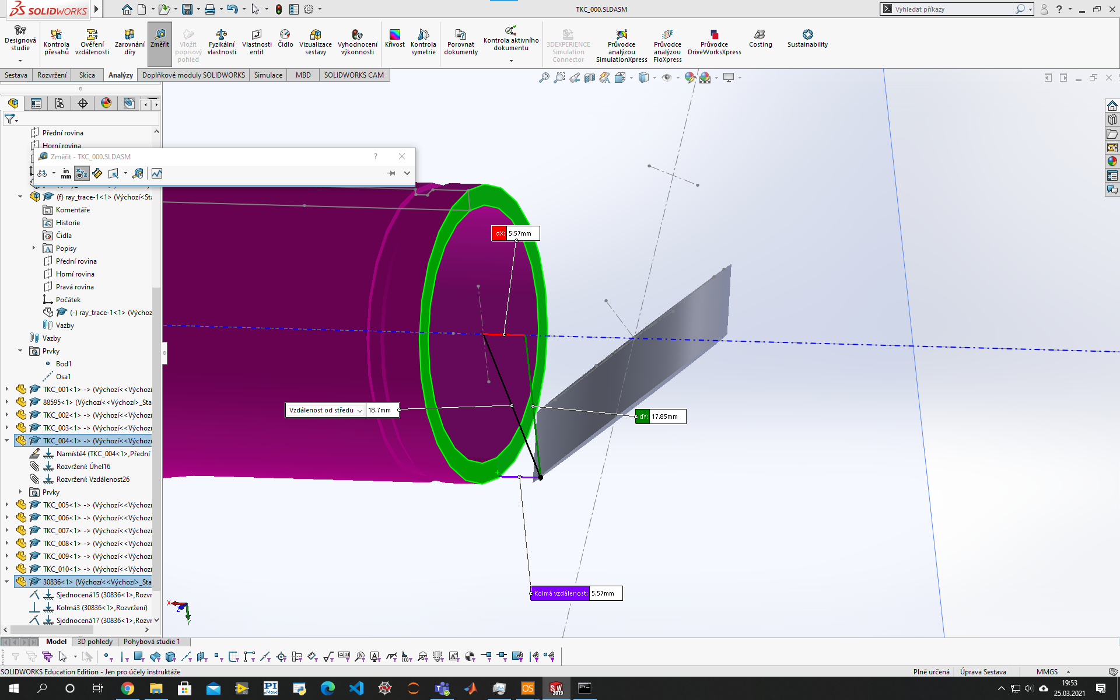
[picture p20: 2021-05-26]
imgs/ulozeni_zrcatka.png

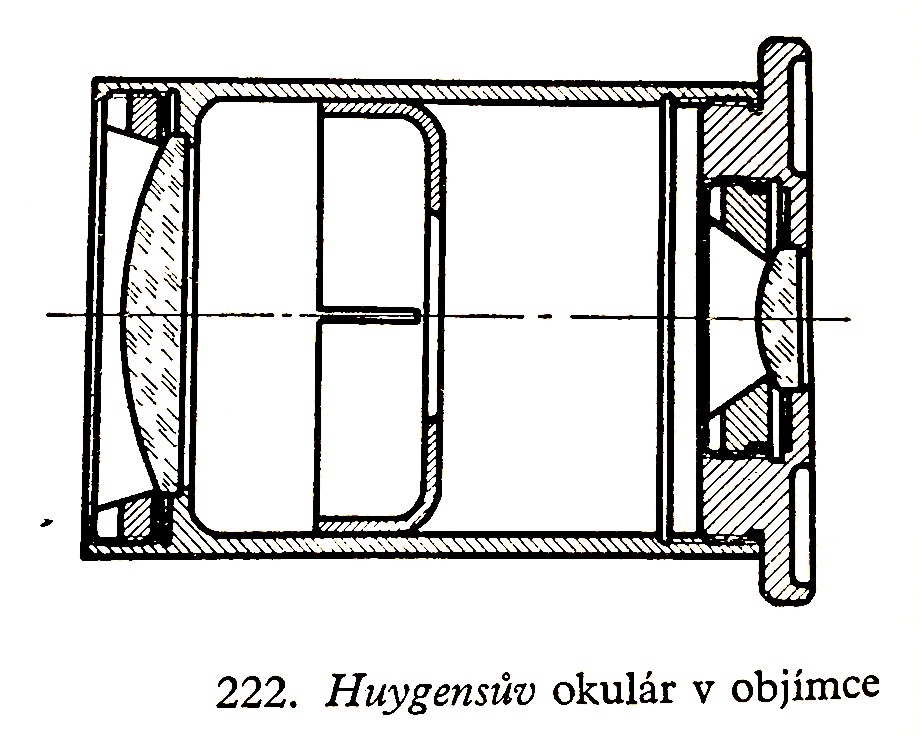
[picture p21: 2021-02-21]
imgs/fh_huygens_ok.jpeg

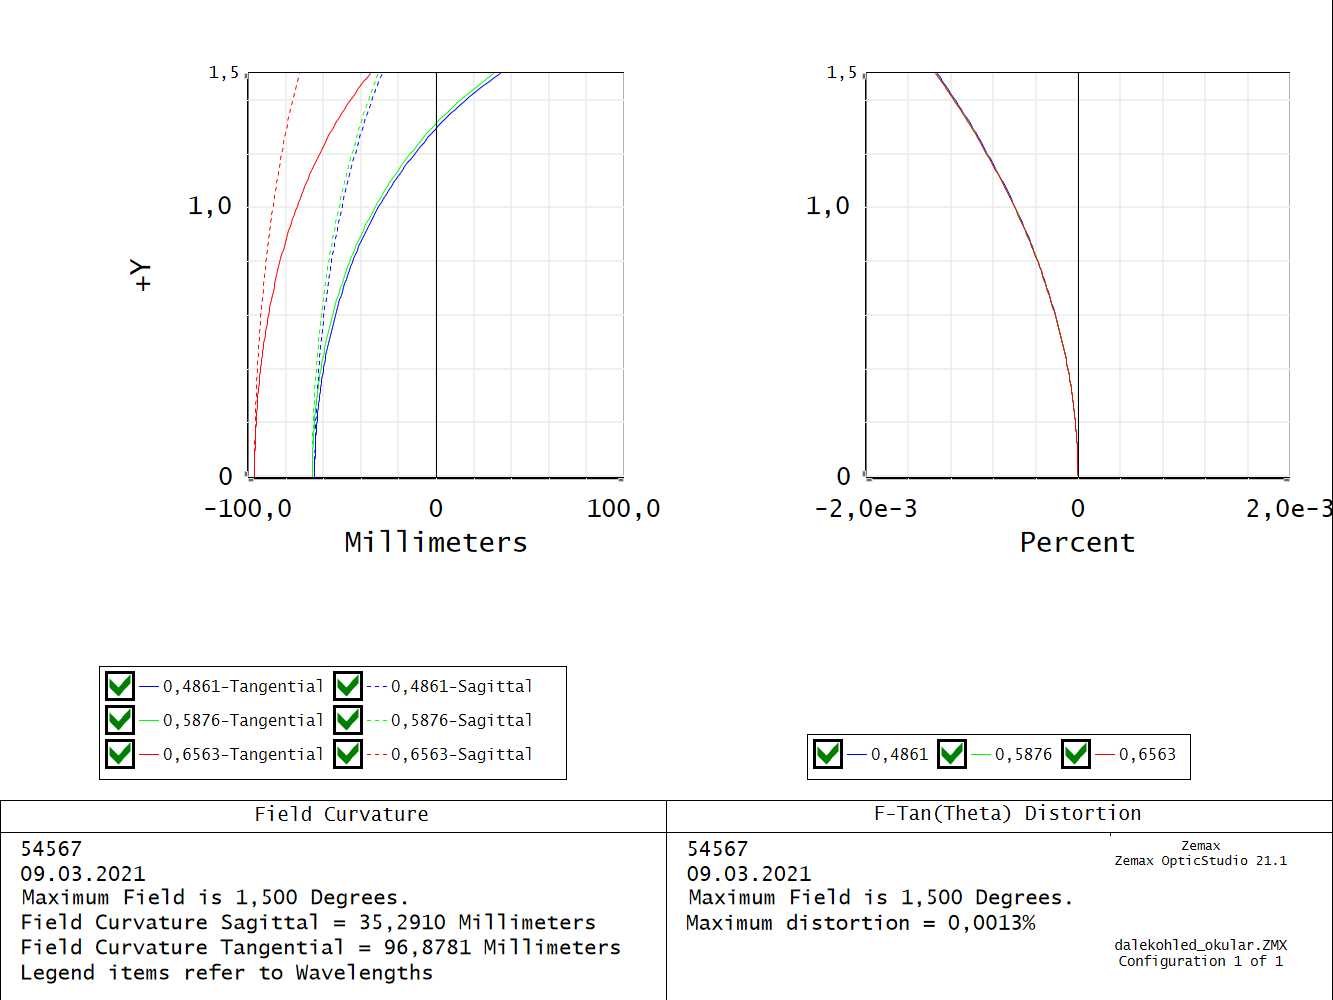
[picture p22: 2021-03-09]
imgs/FieldCurvDist.png

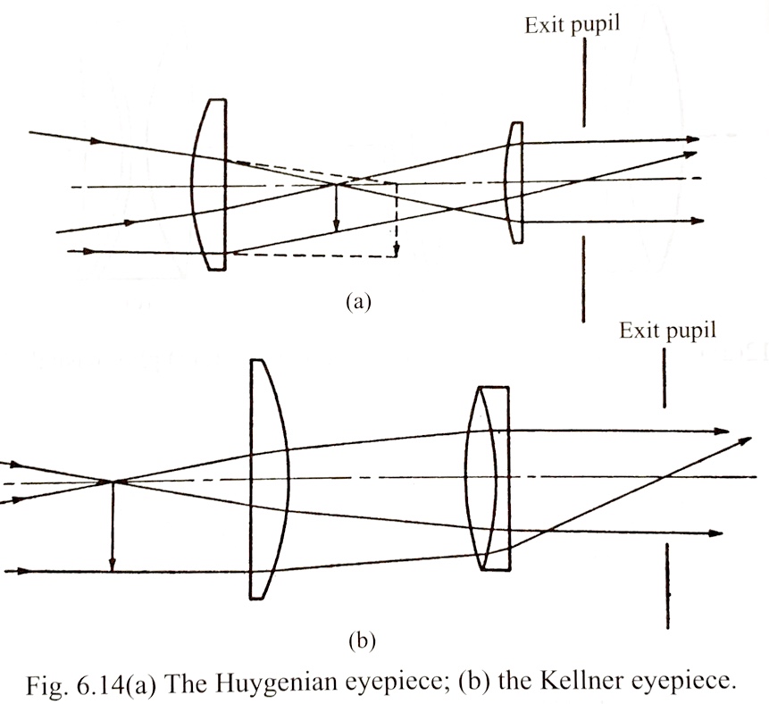
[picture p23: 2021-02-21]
imgs/bw_okulary_schemata.jpg

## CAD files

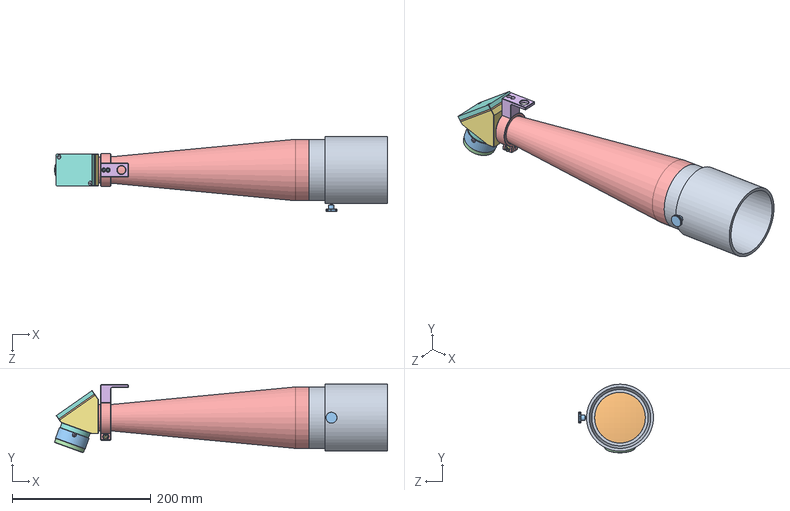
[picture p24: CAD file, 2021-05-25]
CAD/TKC_000.SLDASM
479.5 x 98.8 x 108.0 mm
TKC_001
TKC_002
TKC_003
TKC_004
TKC_005
TKC_006
TKC_007
TKC_008
TKC_009
TKC_011
TKC_010
ISO_2338_1,5h6x6 x 6
TKC_012
TKC_013
ISO_4763_M2,5x5 x 3
TKC_014
DIN_5401_5_mm
F3SS8 x 2
F3SSN1P x 2
ISO_14581_M3x5 x 4
TKC_015
ISO_14581_M3x12 x 2
TKC_016 x 2
TKC_017
TKC_018
TKC_023
TKC_024
ISO_4763_M4x8
ISO_4763_M3x16 x 2
TKC_025
DIN_439_M4
DIN_464_M4x6

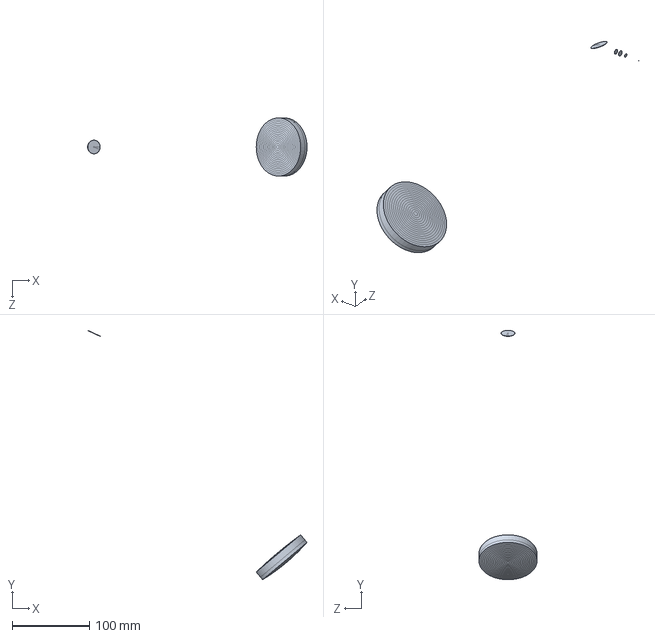
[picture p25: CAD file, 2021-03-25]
CAD/ray_trace-1.sldasm
327.1 x 322.5 x 75.0 mm

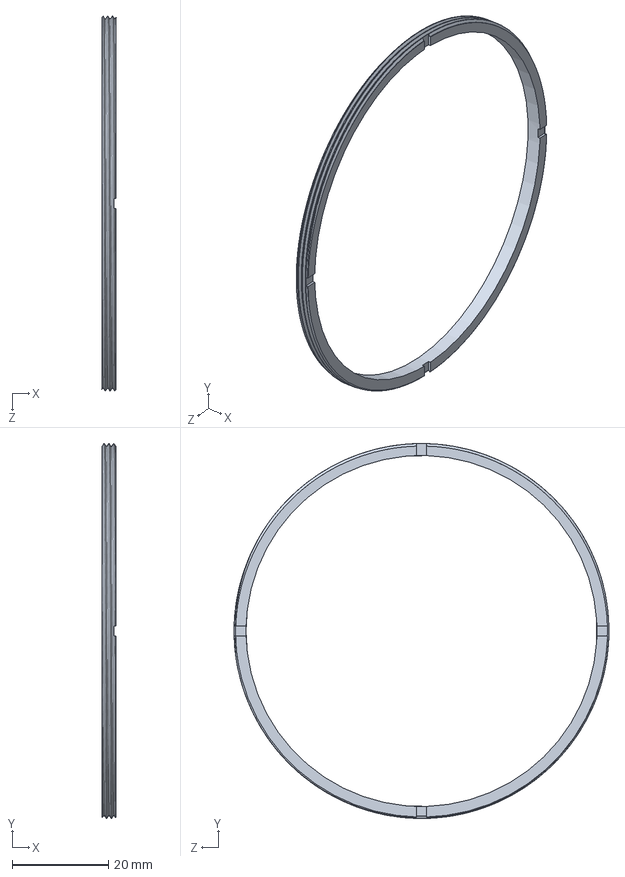
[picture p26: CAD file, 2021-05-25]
CAD/parts/zavitovy_krouzek.SLDPRT
3.00 x 78.0 x 78.0 mm

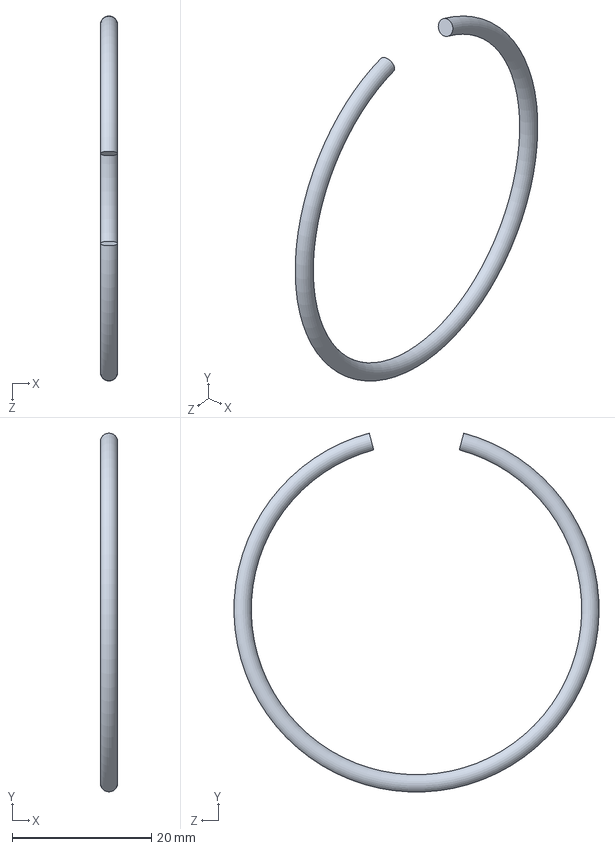
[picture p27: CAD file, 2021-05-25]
CAD/TKC_009.SLDPRT
2.50 x 51.6 x 52.5 mm

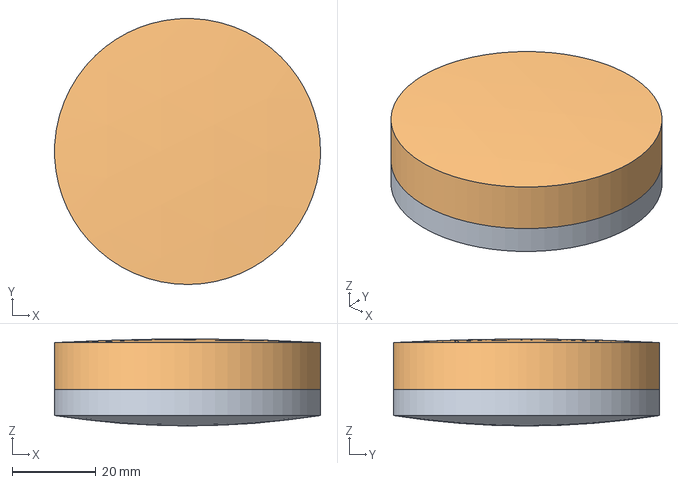
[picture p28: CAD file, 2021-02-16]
parts/objektiv/step_31402.stp
63.5 x 63.5 x 20.8 mm

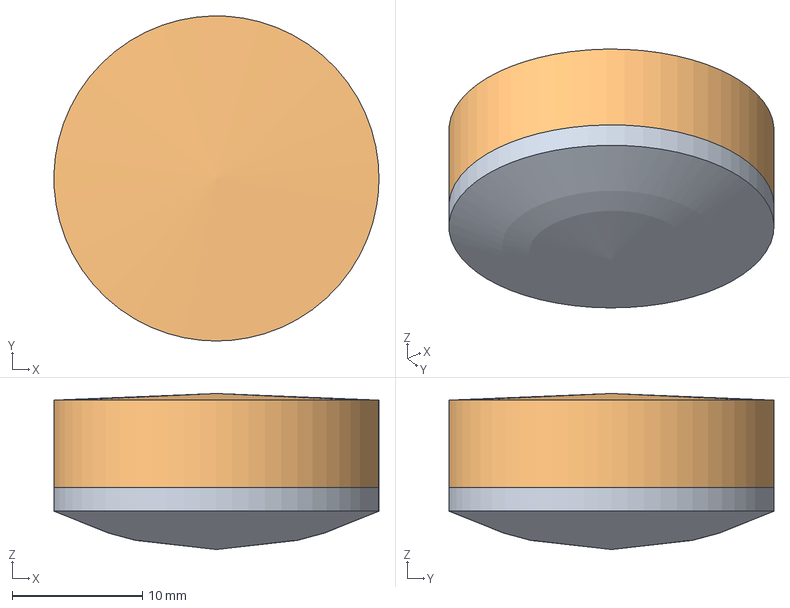
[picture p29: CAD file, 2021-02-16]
parts/okular/iges_32321.igs
25.0 x 25.0 x 12.0 mm

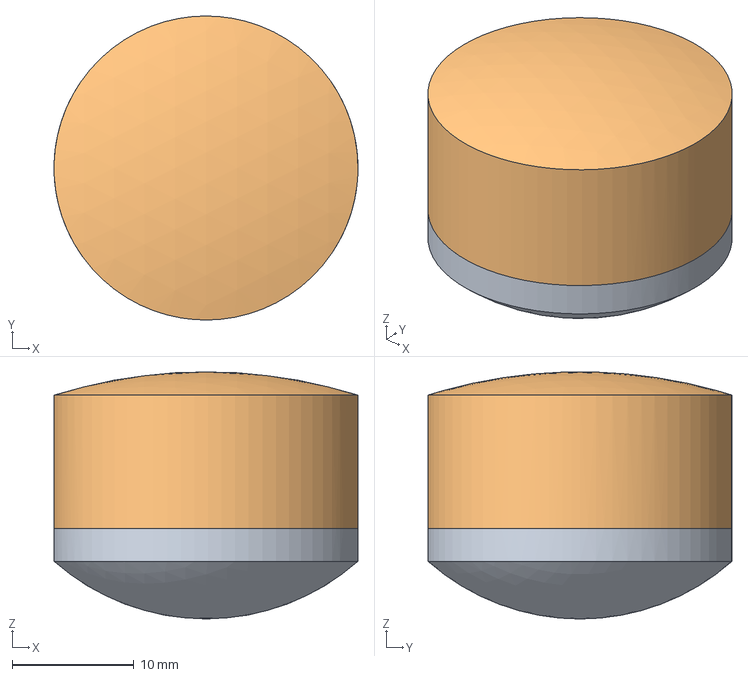
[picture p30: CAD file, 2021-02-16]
parts/okular_20/step_65553.stp
25.0 x 25.0 x 20.3 mm

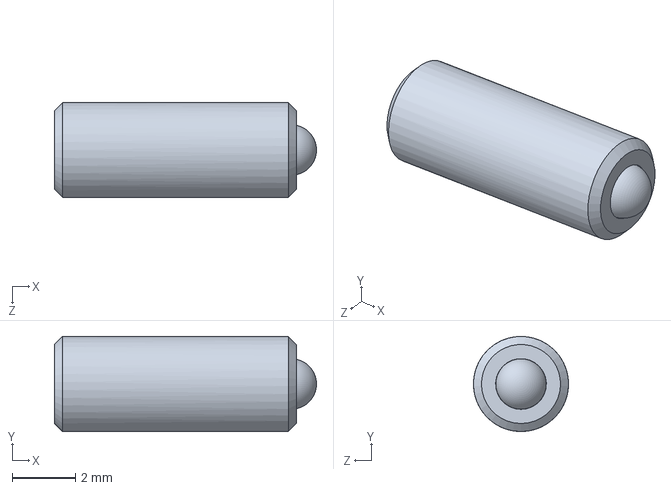
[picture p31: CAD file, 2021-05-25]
CAD/F3SS8.sldprt
8.26 x 3.00 x 2.99 mm

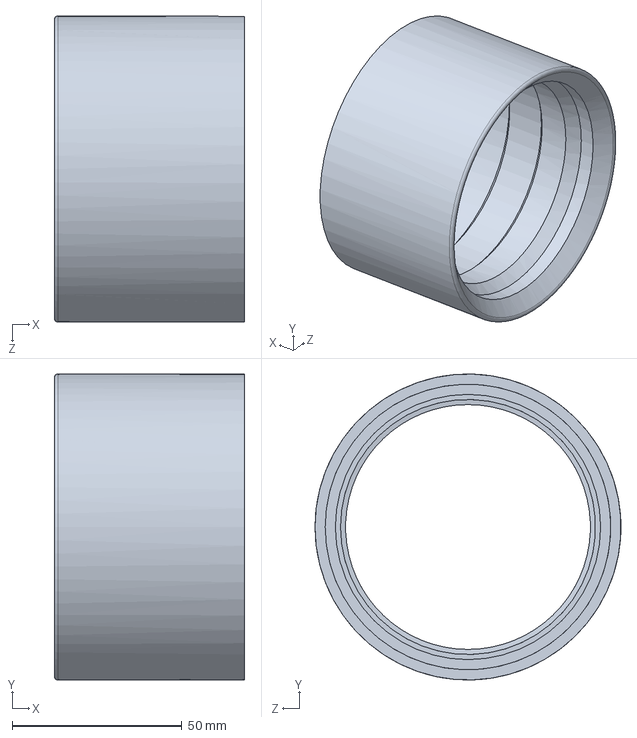
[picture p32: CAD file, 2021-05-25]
CAD/parts/tubus_objektivu.SLDPRT
56.0 x 90.0 x 90.0 mm

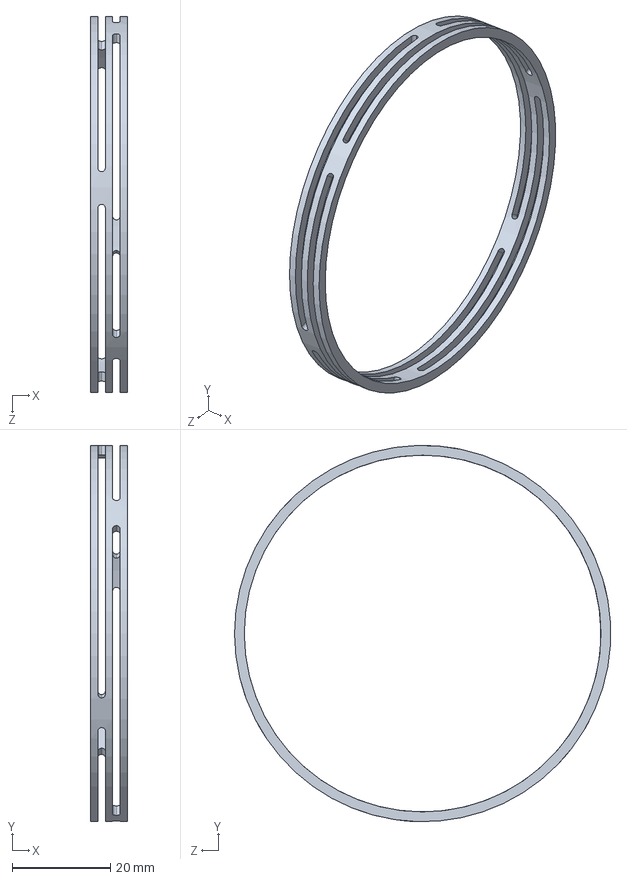
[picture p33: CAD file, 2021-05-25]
CAD/parts/pruzny_krouzek_obj.SLDPRT
7.50 x 76.8 x 76.7 mm

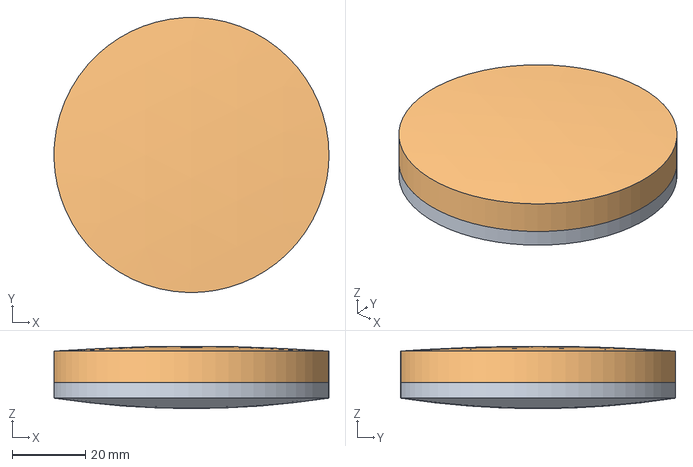
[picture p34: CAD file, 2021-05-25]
CAD/parts/objektiv.stp
75.0 x 75.0 x 17.0 mm

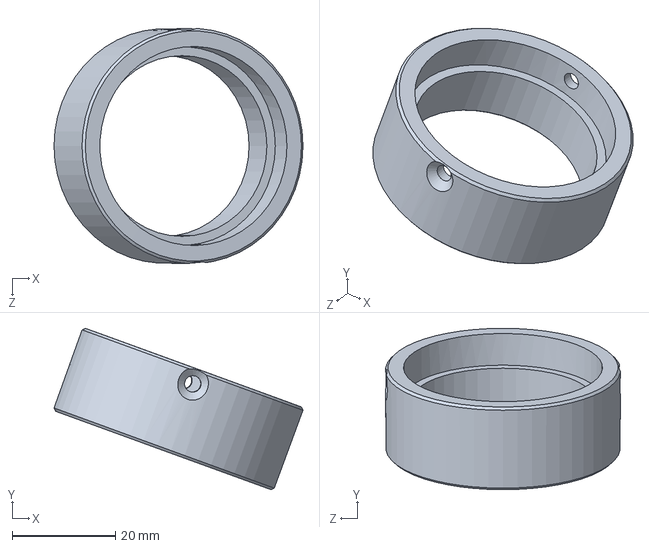
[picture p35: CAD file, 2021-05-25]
CAD/TKC_017.SLDPRT
48.2 x 31.3 x 45.5 mm

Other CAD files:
CAD/ray_trace.sldasm
parts/objektiv/iges_31402.igs
parts/okular/step_32321.stp
parts/okular_20/iges_65553.igs
CAD/30836.SLDPRT
CAD/40800.SLDPRT
CAD/88595.SLDPRT
CAD/DIN_439_M4.sldprt
CAD/DIN_464_M4x6.sldprt
CAD/DIN_5401_5_mm.SLDPRT
CAD/DIN_6885A_2_6.sldprt
CAD/E00630070250S.SLDPRT
CAD/F3SSN1P.sldprt
CAD/ISO_14581_M3x12.sldprt
CAD/ISO_14581_M3x5.sldprt
CAD/ISO_2338_1,5h6x6.sldprt
CAD/ISO_4028_M3x4.sldprt
CAD/ISO_4028_M3x6.sldprt
CAD/ISO_4763_M2,5x5.sldprt
CAD/ISO_4763_M3x16.sldprt
CAD/ISO_4763_M4x8.sldprt
CAD/ISO_8734_2x10.sldprt
CAD/TKC_001.SLDPRT
CAD/TKC_002.SLDPRT
CAD/TKC_003.SLDPRT
CAD/TKC_004.SLDPRT
CAD/TKC_005.SLDPRT
CAD/TKC_006.SLDPRT
CAD/TKC_007.SLDPRT
CAD/TKC_008.SLDPRT
CAD/TKC_010.SLDPRT
CAD/TKC_011.SLDPRT
CAD/TKC_012.SLDPRT
CAD/TKC_013.SLDPRT
CAD/TKC_014.SLDPRT
CAD/TKC_015.SLDPRT
CAD/TKC_016.SLDPRT
CAD/TKC_020.SLDPRT
CAD/TKC_021.SLDPRT
CAD/TKC_022.SLDPRT
CAD/TKC_023.SLDPRT
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

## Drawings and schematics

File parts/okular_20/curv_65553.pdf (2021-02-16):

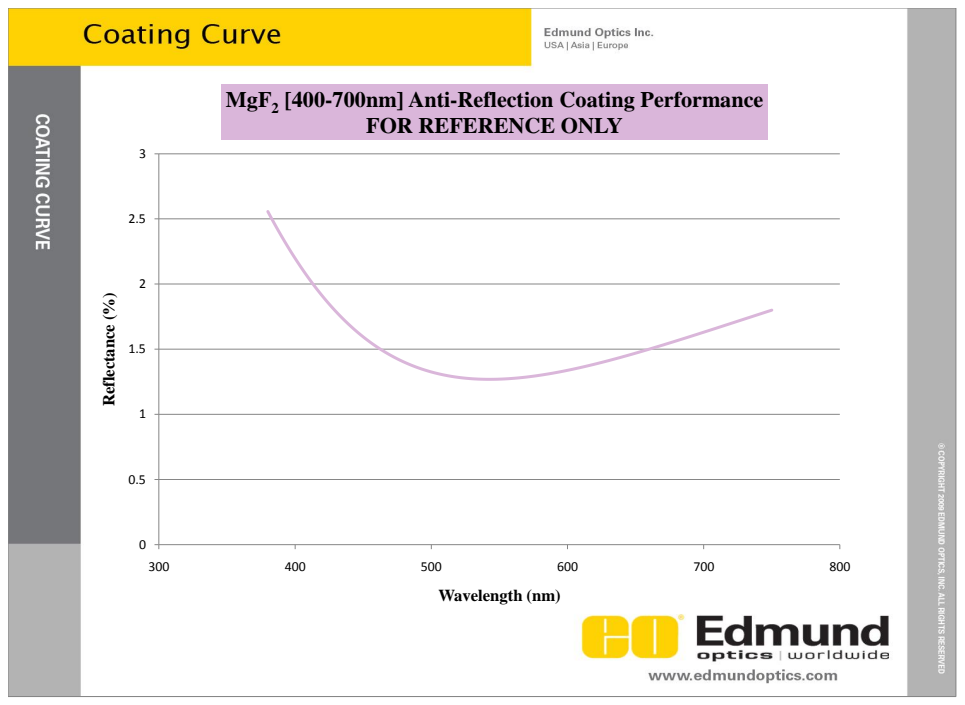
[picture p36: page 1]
Reflectance (%); Wavelength (nm)

[400-700nm] Anti-Reflection Coating Performance
MgF2

FOR REFERENCE ONLY

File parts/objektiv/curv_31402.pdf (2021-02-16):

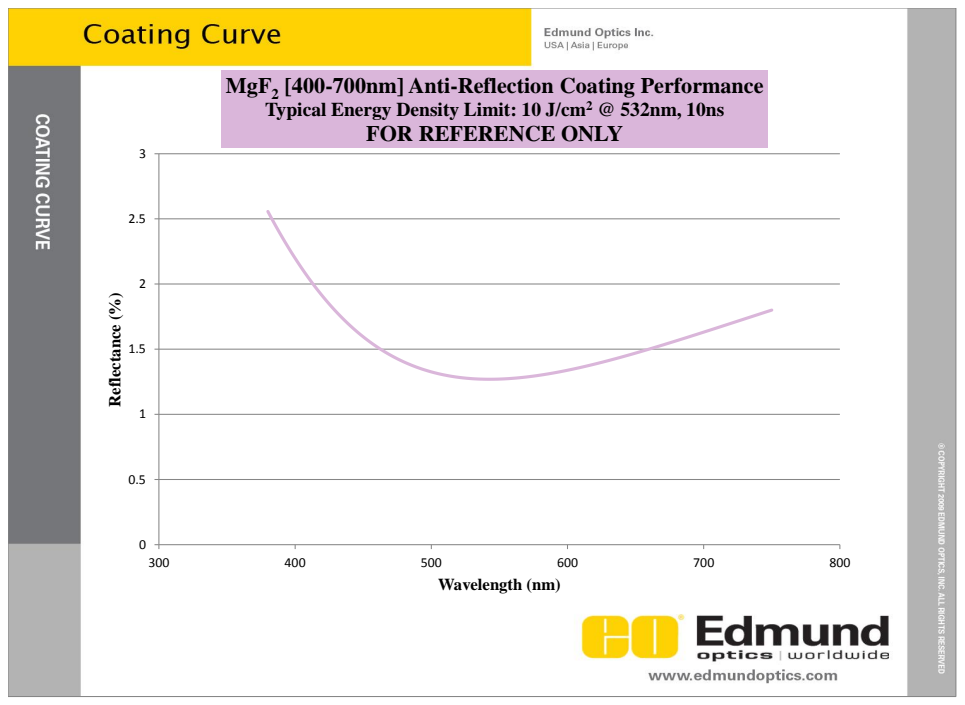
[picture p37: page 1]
Reflectance (%); Wavelength (nm)

[400-700nm] Anti-Reflection Coating Performance
MgF2
Typical Energy Density Limit: 10 J/cm² @ 532nm, 10ns

FOR REFERENCE ONLY

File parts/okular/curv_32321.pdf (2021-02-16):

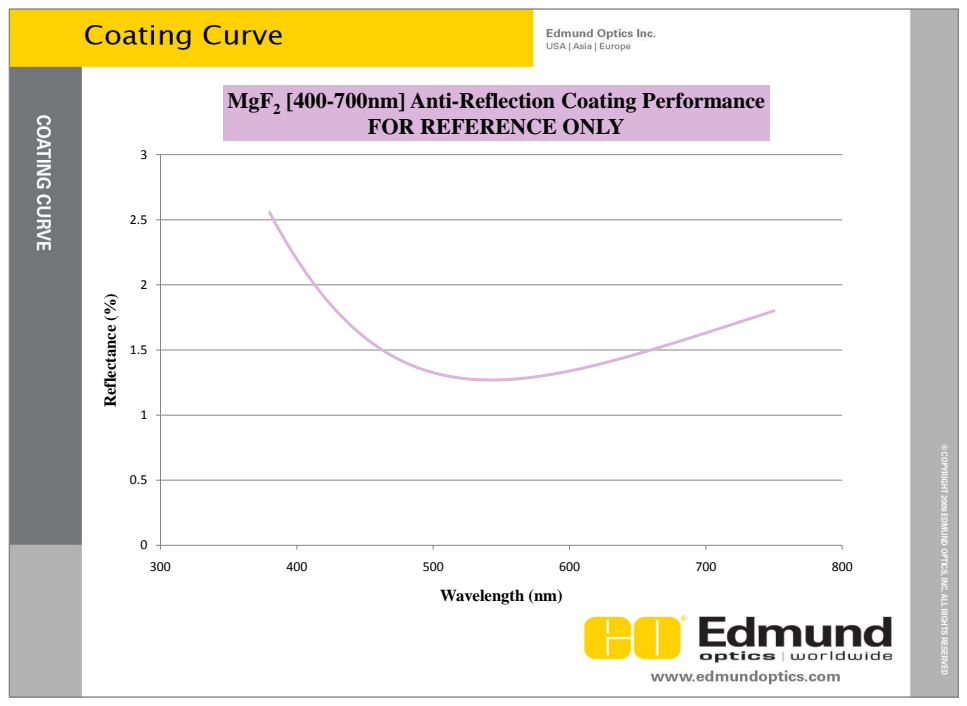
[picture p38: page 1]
Reflectance (%); Wavelength (nm)

[400-700nm] Anti-Reflection Coating Performance
MgF2

FOR REFERENCE ONLY

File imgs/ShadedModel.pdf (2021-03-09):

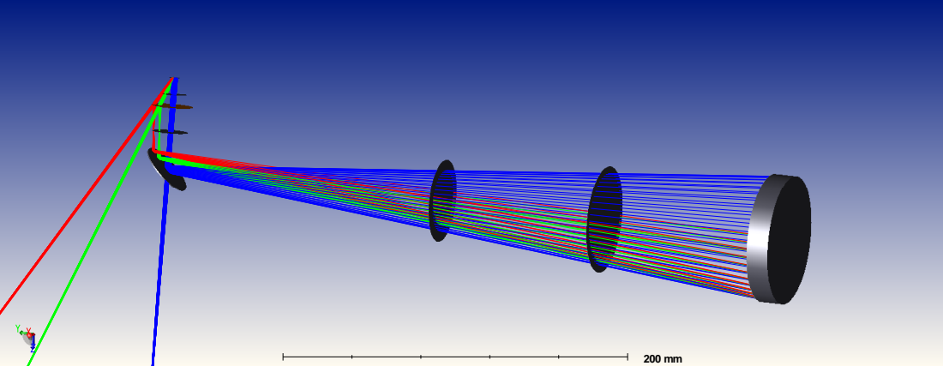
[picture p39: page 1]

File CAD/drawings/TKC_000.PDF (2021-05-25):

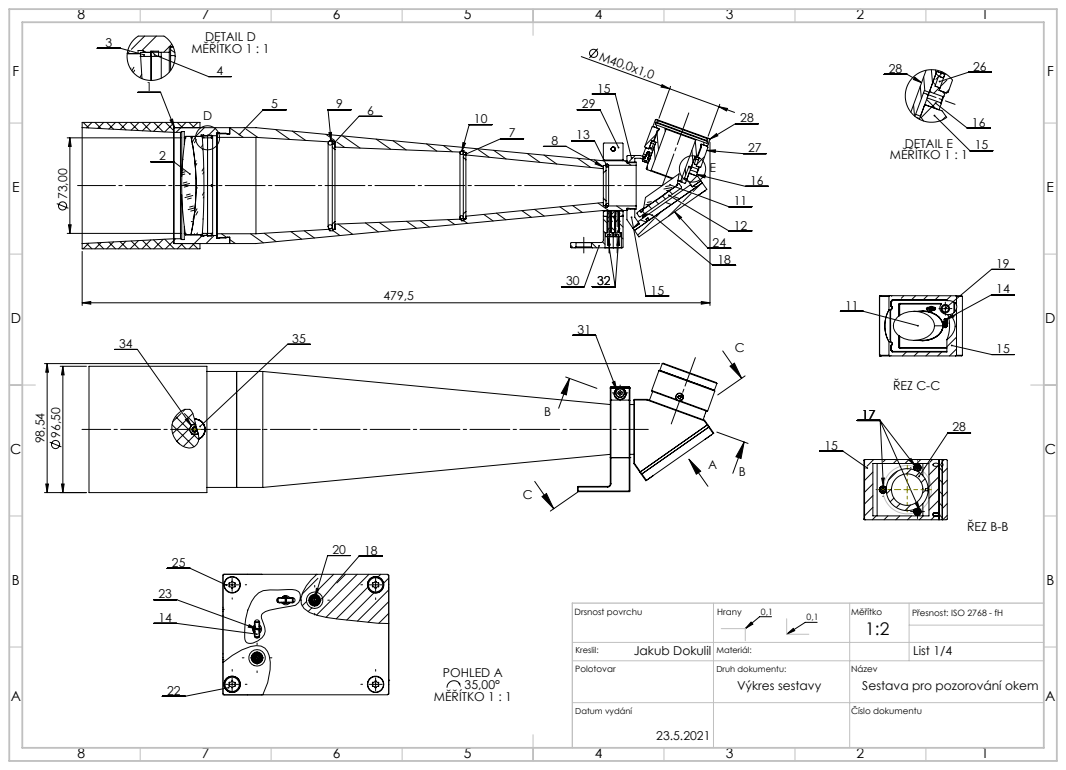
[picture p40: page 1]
POHLED A 35,00° MĚŘÍTKO 1 : 1 22; ŘEZ B-B; DETAIL D MĚŘÍTKO 1 : 1 3; DETAIL E MĚŘÍTKO 1 : 1; ŘEZ C-C

Drsnost povrchu | Hrany 0,1 | Měřítko 1:2 | Přesnost: ISO 2768 - fH 0,1

Kreslil: Jakub Dokulil | Materiál: | | List 1/4
Polotovar | Druh dokumentu: Výkres sestavy | Název Sestava pro pozorování okem

Datum vydání 23.5.2021 | | Číslo dokumentu

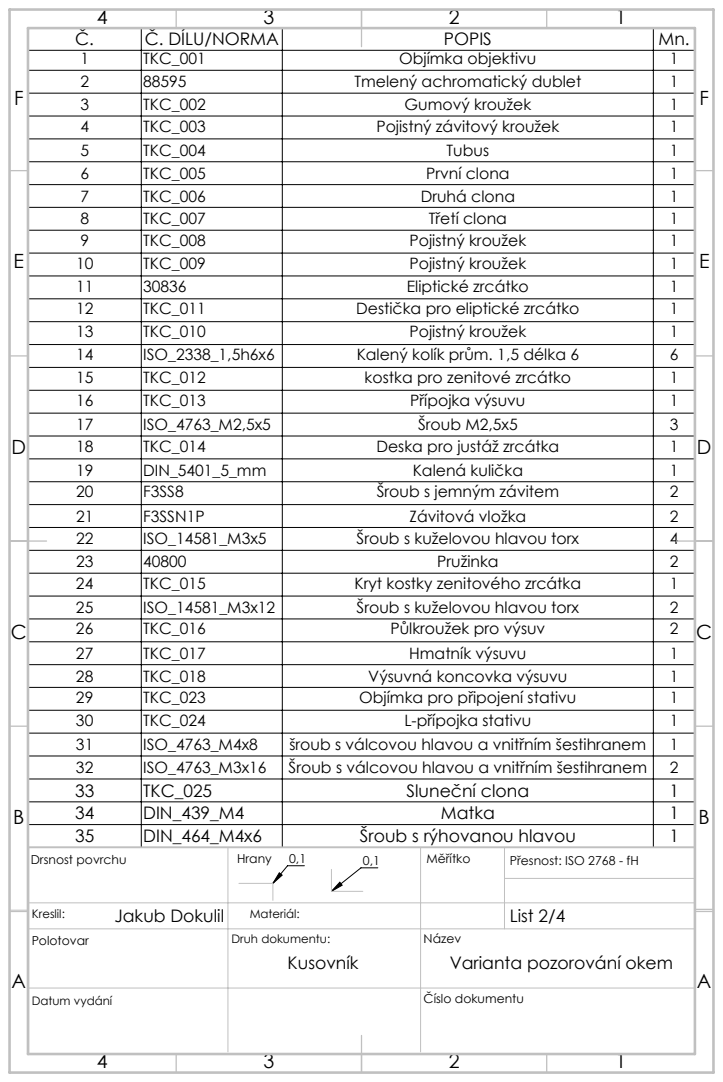
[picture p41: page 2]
Č. DÍLU/NORMA; POPIS; TKC_001; Objímka objektivu; Tmelený achromatický dublet; TKC_002; Gumový kroužek; TKC_003; Pojistný závitový kroužek; TKC_005; První clona; TKC_006; Druhá clona; TKC_007; Třetí clona; TKC_008; Pojistný kroužek; TKC_009; Eliptické zrcátko; TKC_011; Destička pro eliptické zrcátko; TKC_010; ISO_2338_1,5h6x6; Kalený kolík prům. 1,5 délka 6; TKC_012; kostka pro zenitové zrcátko; TKC_013; Přípojka výsuvu; ISO_4763_M2,5x5; Šroub M2,5x5; TKC_014; Deska pro justáž zrcátka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

Jakub Dokulil Kreslil: | Materiál: | | List 2/4
Polotovar | Druh dokumentu: Kusovník | Název Varianta pozorování okem

Číslo dokumentu

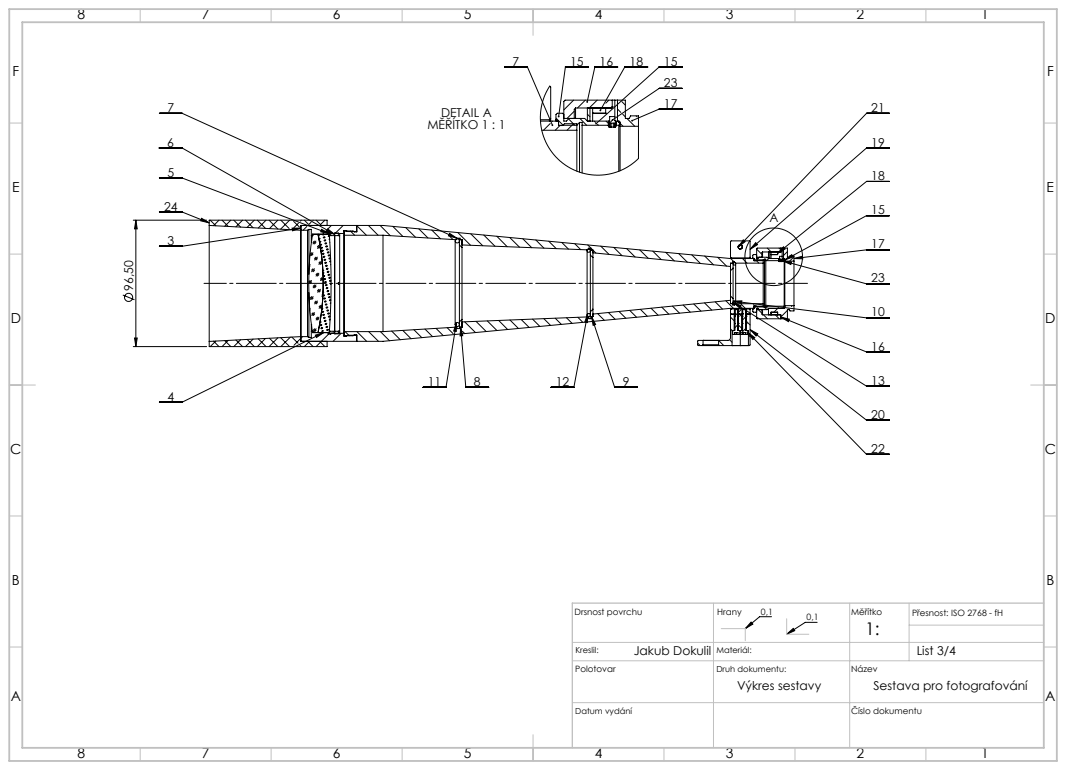
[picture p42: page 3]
DETAIL A; MĚŘÍTKO 1 : 1; Výkres sestavy A

Drsnost povrchu | Hrany 0,1 | Měřítko 1: | Přesnost: ISO 2768 - fH 0,1

Kreslil: Jakub Dokulil | Materiál: | | List 3/4
Polotovar | Druh dokumentu: | Název Sestava pro fotografování

Číslo dokumentu

Č. POLOŽKY | Č. DÍLU | | POPIS | Množství
3 | TKC_001 | Objímka objektivu | | 1
4 | 88595 | Tmelený achromatický dublet | | 1
5 | TKC_002 | Gumový kroužek | | 1
6 | TKC_003 | Pojistný závitový kroužek | | 1
E | | | | | E
7 | TKC_004 | Tubus | | 1
8 | TKC_005 | První clona | | 1
9 | TKC_006 | Druhá clona | | 1
10 | TKC_007 | Třetí clona | | 1
11 | TKC_008 | Pojistný kroužek | | 1
12 | TKC_009 | Pojistný kroužek | | 1
13 | TKC_010 | Pojistný kroužek | | 1
14 | ISO_14581_M3x5 | Šroub s kuželovou hlavou torx | | 2
15 | TKC_019 | Vnitřek výsuvu pro fotoaparát | | 1
16 | TKC_020 | Hmatník pro fotografování | | 1
17 | TKC_021 | Pohyblivá část výsuvu s bajonetem | | 1
18 | TKC_022 | Půlkroužek | | 2
19 | TKC_023 | Objímka pro připojení stativu | | 1
20 | TKC_024 | L-přípojka stativu | | 1
21 | ISO_4763_M4x8 | šroub s válcovou hlavou a vnitřním šestihranem | | 1
22 | ISO_4763_M3x16 | Šroub s válcovou hlavou a vnitřním šestihranem | | 2
23 | ISO_4028_M3x4 | Set screw with dog point stainless steel A4 M3x4 | | 1
24 | TKC_025 | Sluneční clona | | 1
25 | DIN_439_M4 | Matka | | 1
26 | DIN_464_M4x6 | Šroub s rýhovanou hlavou | | 1
A | A
B | B
C | C
D | D
F | F
Jakub Dokulil Kreslil: | Materiál: | | List 4/4
Polotovar | Druh dokumentu: Kusovník | Název Varianta fotografování
| | Číslo dokumentu
Drsnost povrchu | Hrany 0,1 | 0,1 | Měřítko | Přesnost: ISO 2768 - fH

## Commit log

2021-02-16 v prubehu druheho cvika
    [iges_31402.igs, iges_32321.igs, step_31402.stp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]
2021-02-16 utery konec
    [iges_31402.igs, iges_32321.igs, iges_65553.igs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]
2021-03-25 CAD parts
    [30836.SLDPRT, 88595.SLDPRT, TKC_000.SLDASM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]
2021-04-02 updatík :)
    [DIN_5401_5_mm.SLDPRT, DIN_6885A_2_6.sldprt, ISO_2338_1,5h6x6.sldprt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]
2021-04-27 Sestava a díly před dokončím, jen přidat kor. oka
    [30836.SLDPRT, 40800.SLDPRT, 88595.SLDPRT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]
2021-04-27 výkres sestavy, uvidíme rozhození po úpravách
    [TKC_000.SLDDRW]
2021-04-27 uložené změny před rozrýpáním
    [TKC_000.SLDASM, TKC_017.SLDPRT, TKC_018.SLDPRT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]
2021-04-27 dalekohled je bez vážných chyb s opravenými vadami
    [TKC_000.SLDASM, TKC_013.SLDPRT, TKC_016.SLDPRT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]
2021-05-25 Výkresy dokresleny!
    [30836.SLDPRT, 40800.SLDPRT, DIN_439_M4.sldprt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]
